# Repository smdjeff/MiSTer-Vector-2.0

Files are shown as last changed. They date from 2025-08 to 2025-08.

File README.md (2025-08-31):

## MisterArcade
## DE10-Nano adapter board for vector graphics output

* Modern, 3W mono onboard amplifier
* No slow or overclocked serial DACs. Latched, high speed, low cost R–2R ladder to perform digital-to-analog conversion
* Uses DE10-Nano GPIO1 2x20 connector for input from FPGA (GPIO2 remains free for standard MisterArcade RAM expansion)
* No USB latency
* JAMMA IO with ESD protection

* 10bit +/- 10v X output
* 10bit +/- 10v Y output
* 6bit 0-3.3v RED output
* 6bit 0-3.3v GREEN output
* 6bit 0-3.3v BLUE output

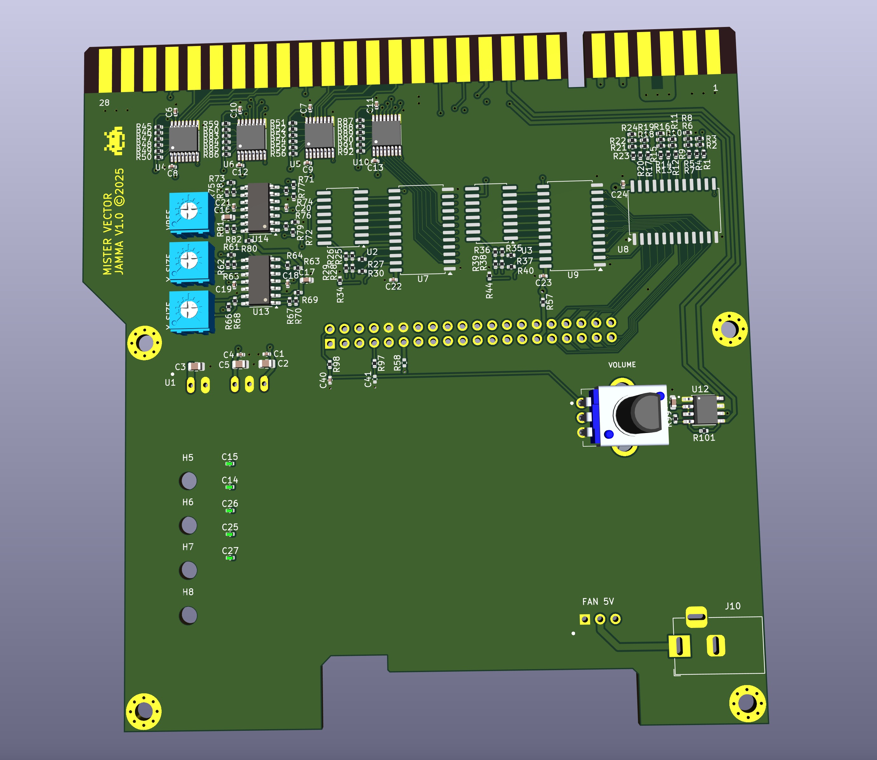
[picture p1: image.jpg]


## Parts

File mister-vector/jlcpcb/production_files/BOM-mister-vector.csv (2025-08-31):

Comment | Designator | Footprint | LCSC | Quantity
75R | R61,R62,R66,R67,R71,R72,R73,R80 | R_0402_1005Metric | C114757 | 8
475R | R97,R98 | R_0402_1005Metric | C137975 | 2
1uF | C16,C17,C47 | C_0603_1608Metric | C15849 | 3
0 | R57 | R_0402_1005Metric | C17168 | 1
4.7uF | C2,C3,C5 | C_0805_2012Metric | C1779 | 3
100k | R45,R46,R47,R48,R49,R50,R51,R52,R53,R54,R55,R56,R59,R60,R83,R84,R85,R86,R87,R88,R89,R90,R91,R92 | R_0402_1005Metric | C25741 | 24
10K | R63,R64,R65,R68,R69,R70,R74,R75,R76,R81 | R_0402_1005Metric | C25744 | 10
20k | R101,R99 | R_0402_1005Metric | C25765 | 2
4K7 | R77,R78,R79,R82 | R_0402_1005Metric | C25900 | 4
TL084HIDR | U13,U14 | SOIC-14_3.9x8.7mm_P1.27mm | C2878714 | 2
100nF | C1,C10,C11,C12,C13,C18,C19,C20,C21,C22,C23,C24,C4,C6,C7,C8,C9 | C_0402_1005Metric | C307331 | 17
TXB0106PWR | U10,U4,U5,U6 | SOP65P640X120-16N | C38253 | 4
20nF | C40 | C_0402_1005Metric | C5448807 | 1
LM4871MX_NOPB | U12 | SOIC127P599X175-8N | C7554 | 1
VREF | VR1,VR2,VR3 | TRIM_3362P-1-203LF | C81263 | 3
100k 0.1% | R1,R10,R11,R12,R13,R14,R15,R16,R17,R18,R19,R2,R20,R21,R22,R23,R24,R25,R26,R27,R28,R29,R3,R30,R31,R32,R33,R34,R35,R36,R37,R38,R39,R4,R40,R41,R42,R43,R44,R5,R6,R7,R8,R9 | R_0402_1005Metric | C852472 | 44

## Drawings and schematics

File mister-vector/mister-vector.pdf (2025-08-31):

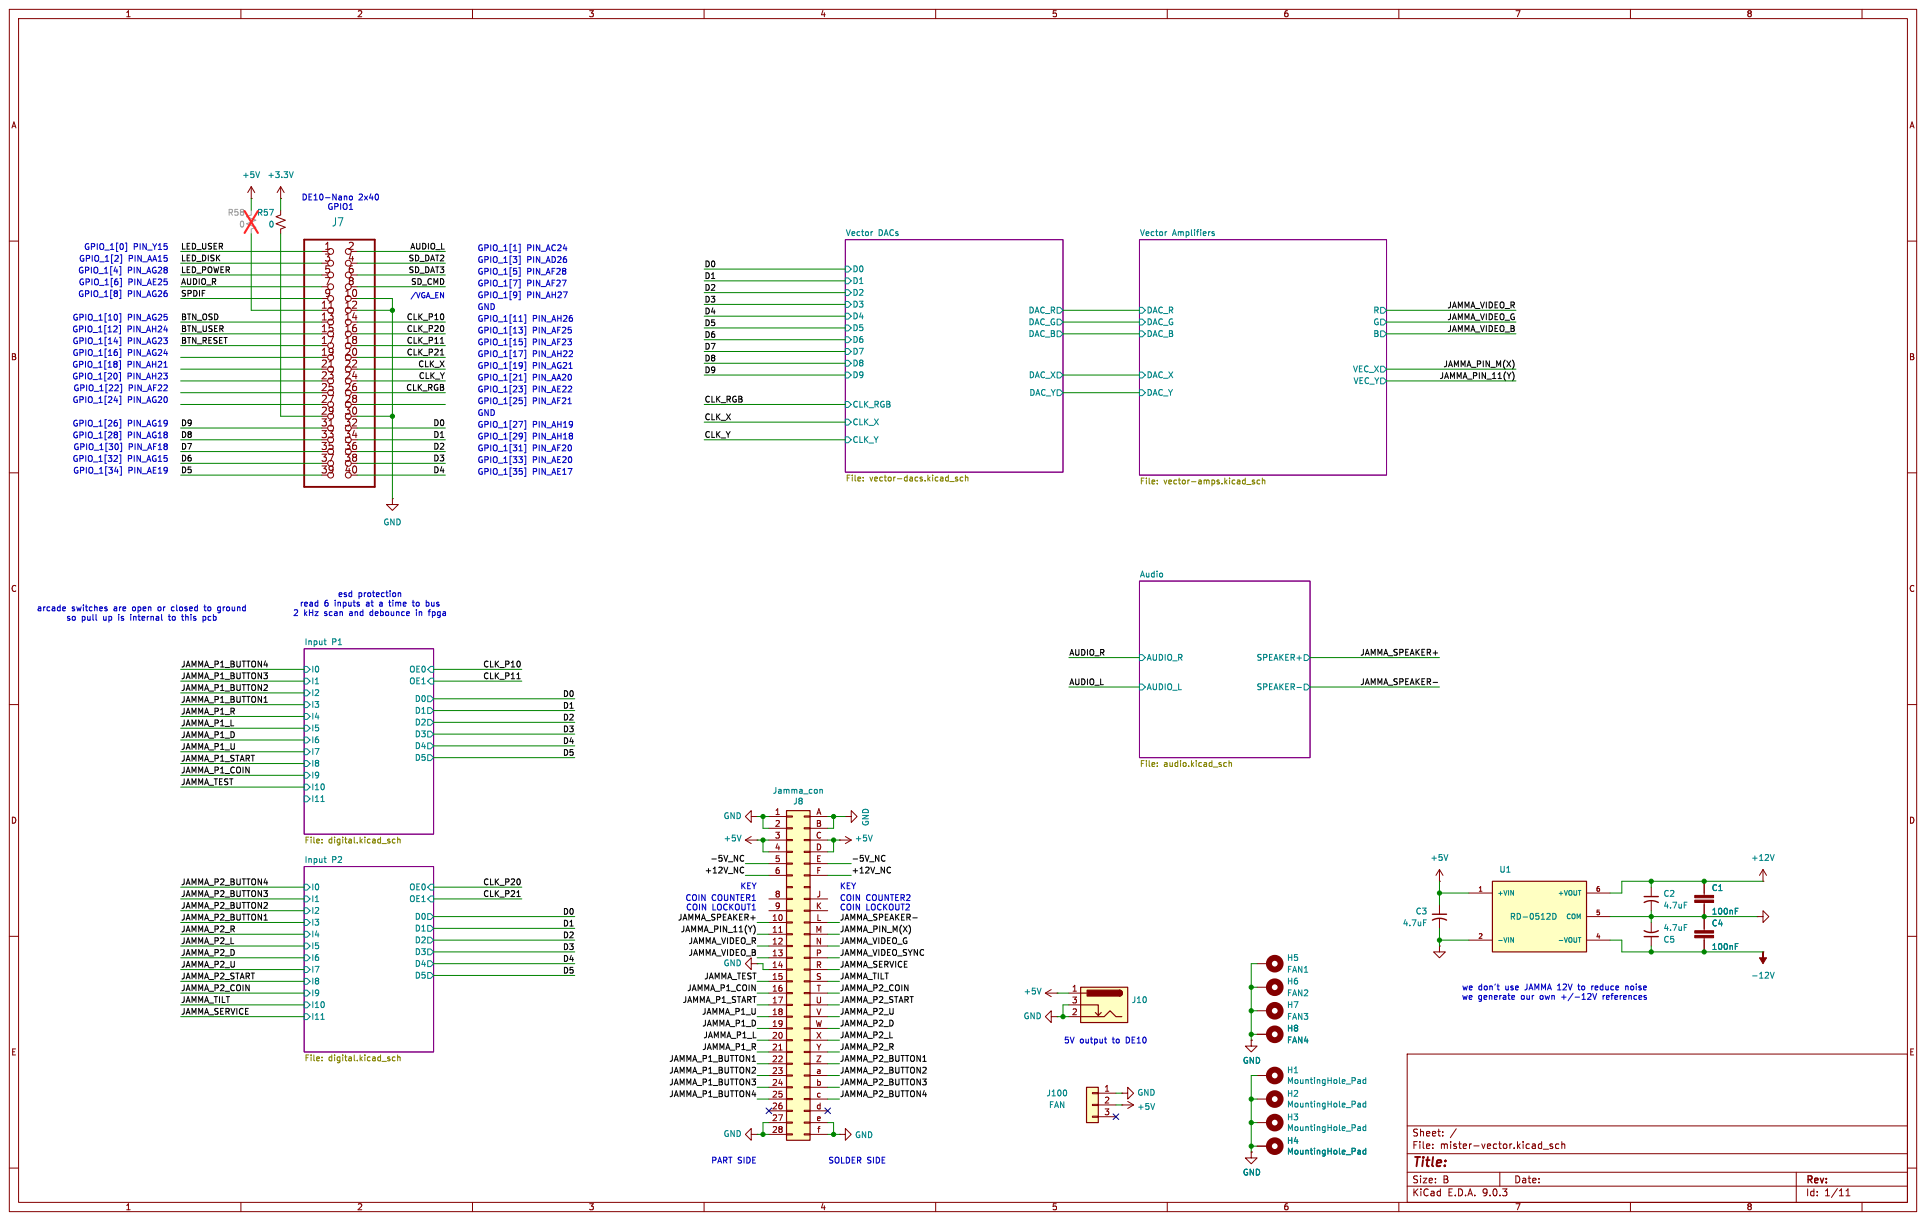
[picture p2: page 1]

Vector DACs File: vector-dacs.kicad_sch

arcade switches are open or closed to ground

read 6 inputs at a time to bus 2 kHz scan and debounce in fpga

Id: 1/11 Title: File: mister-vector.kicad_sch Sheet: /

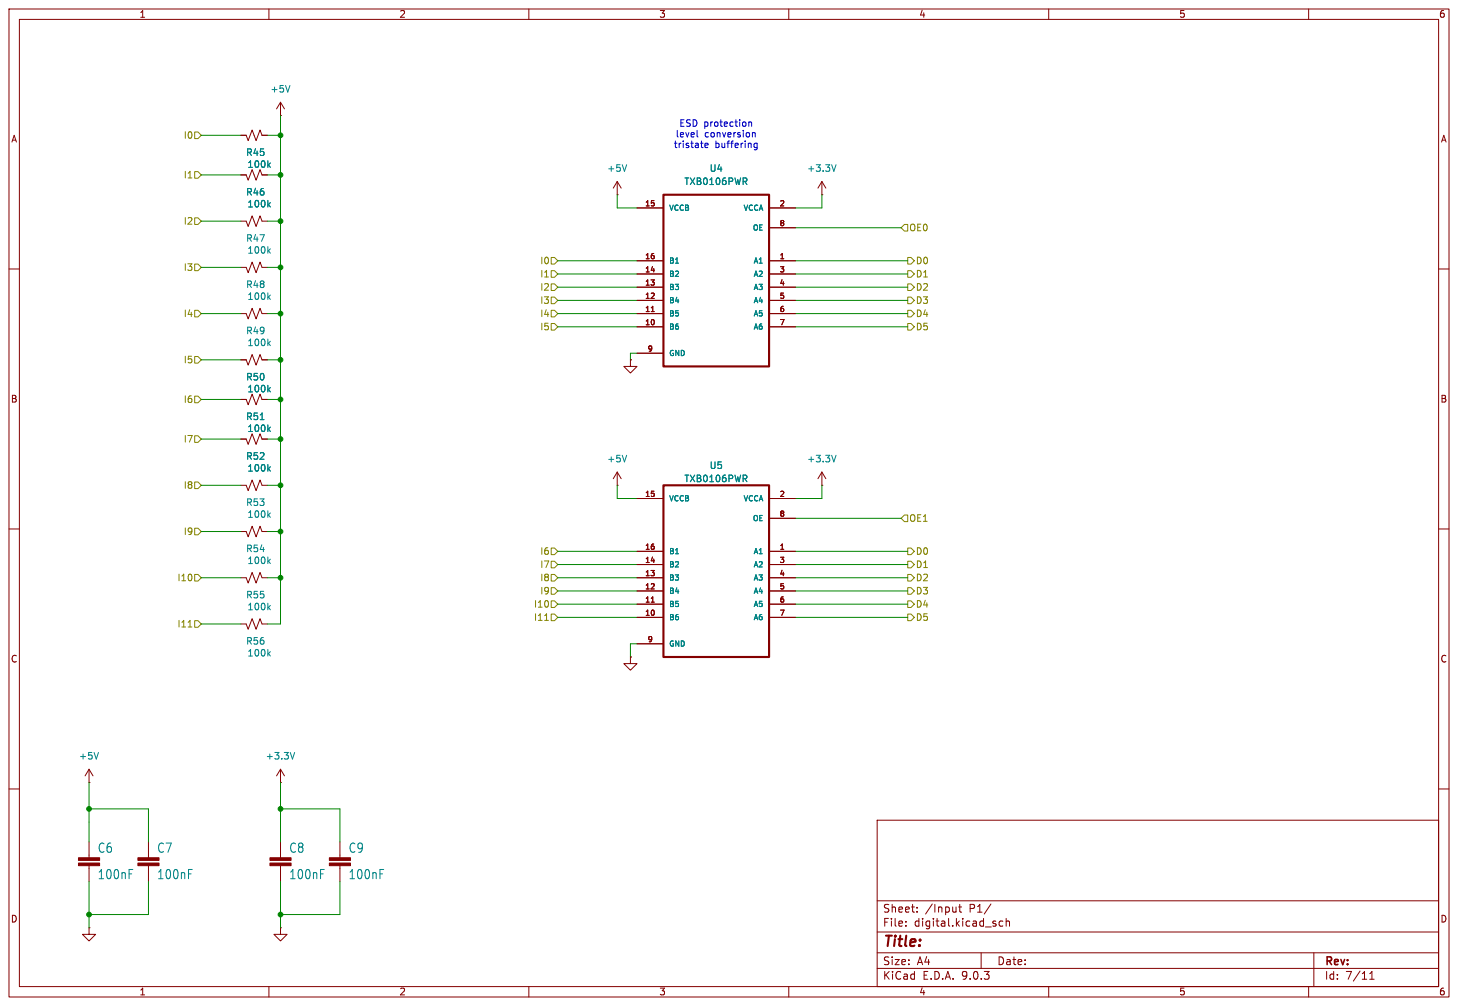
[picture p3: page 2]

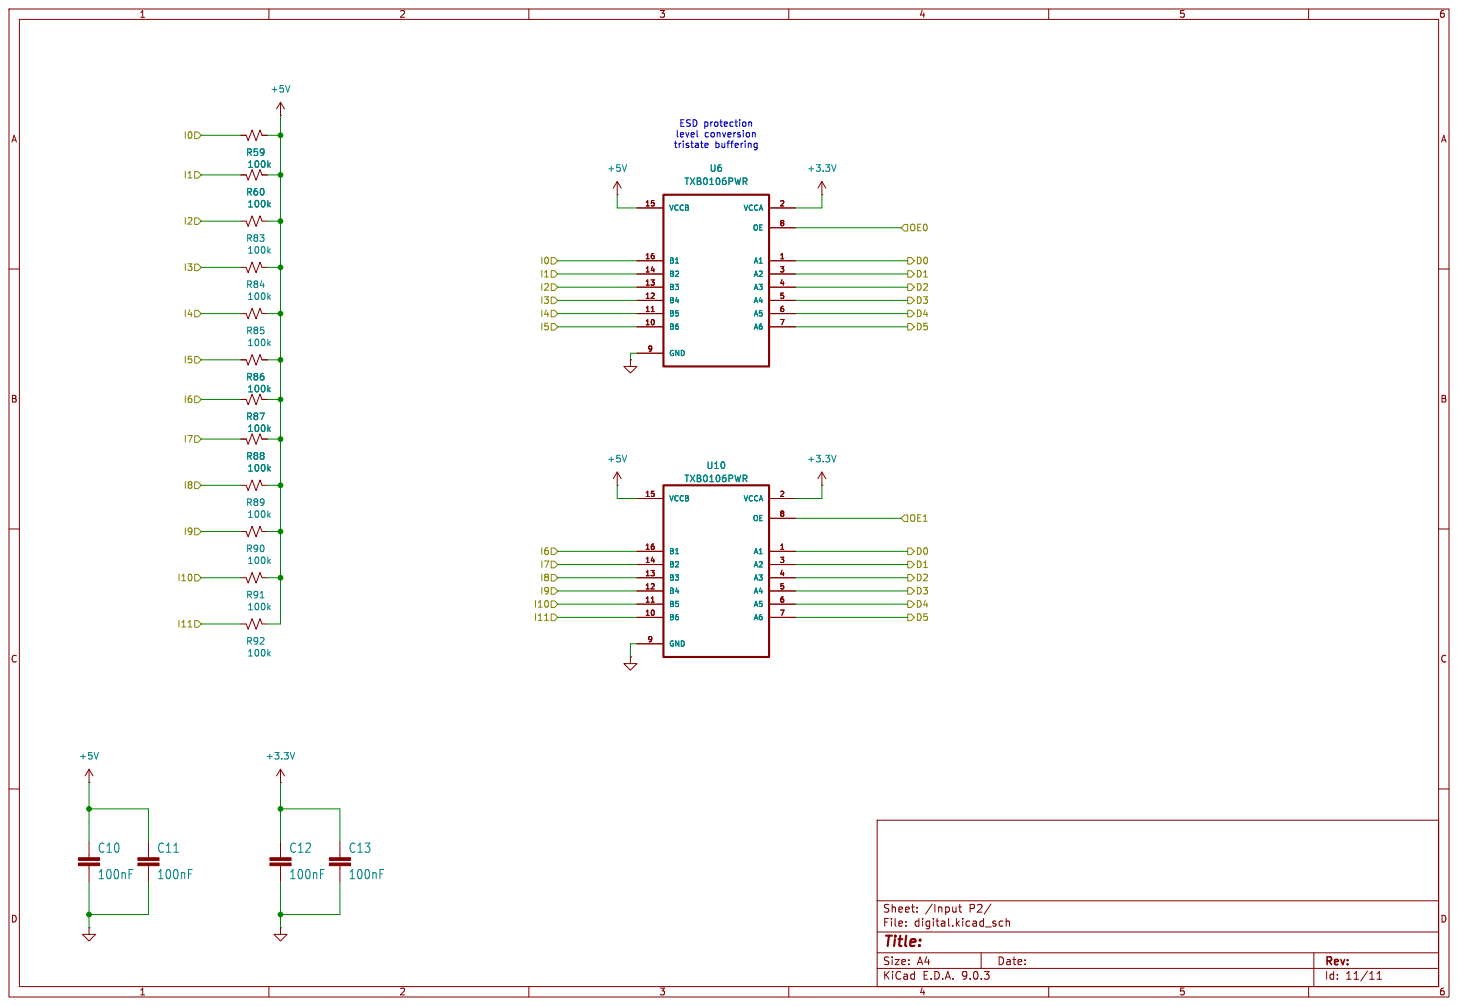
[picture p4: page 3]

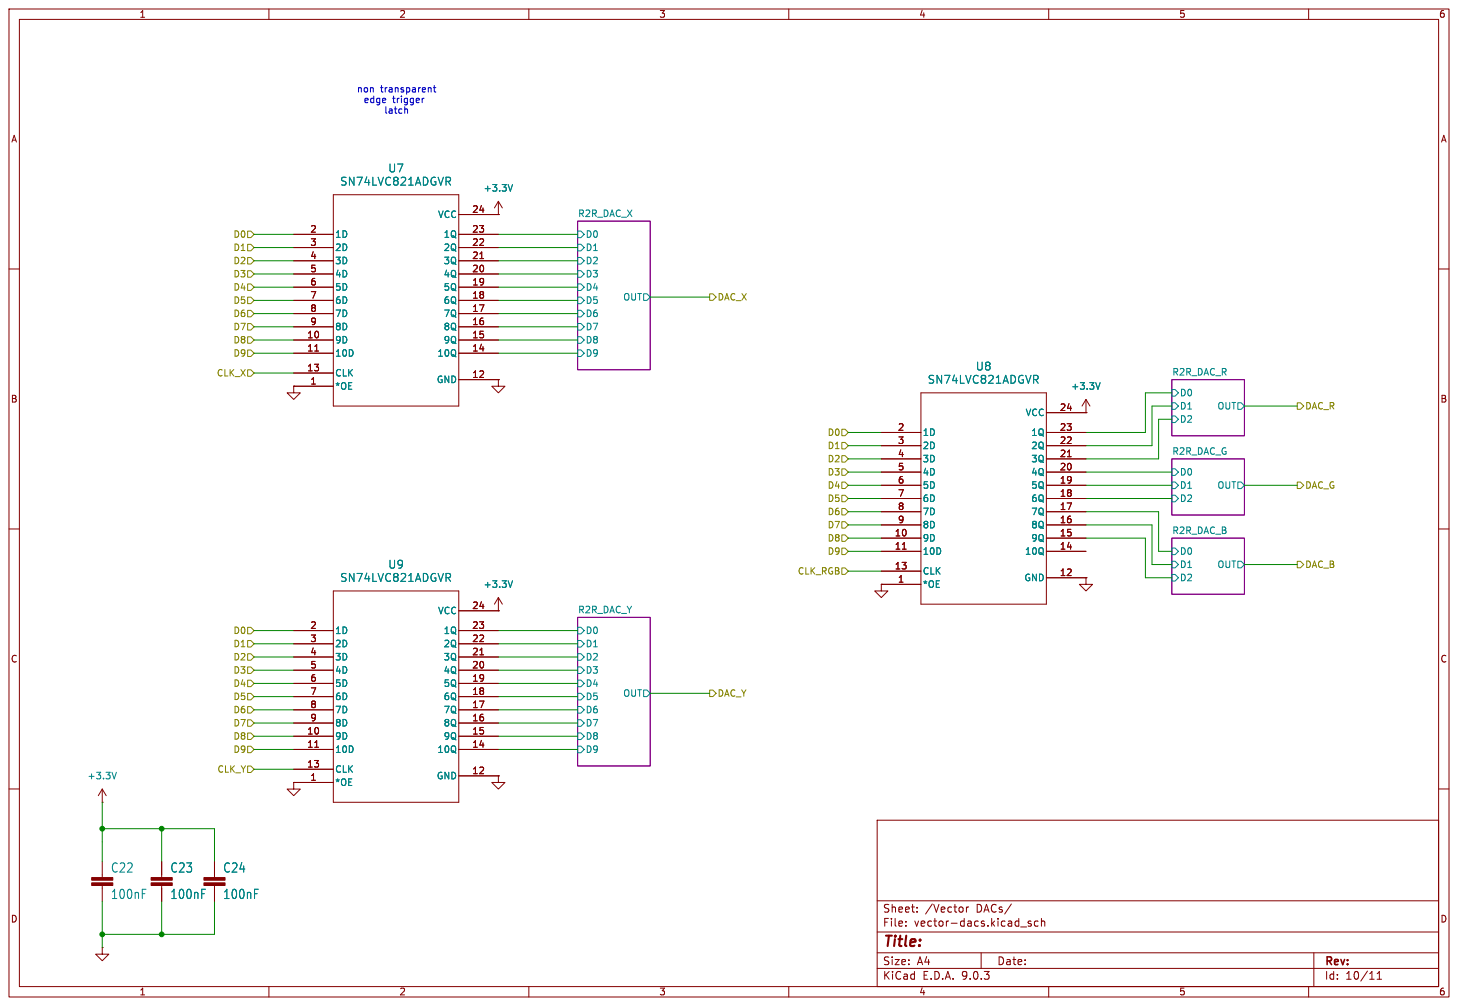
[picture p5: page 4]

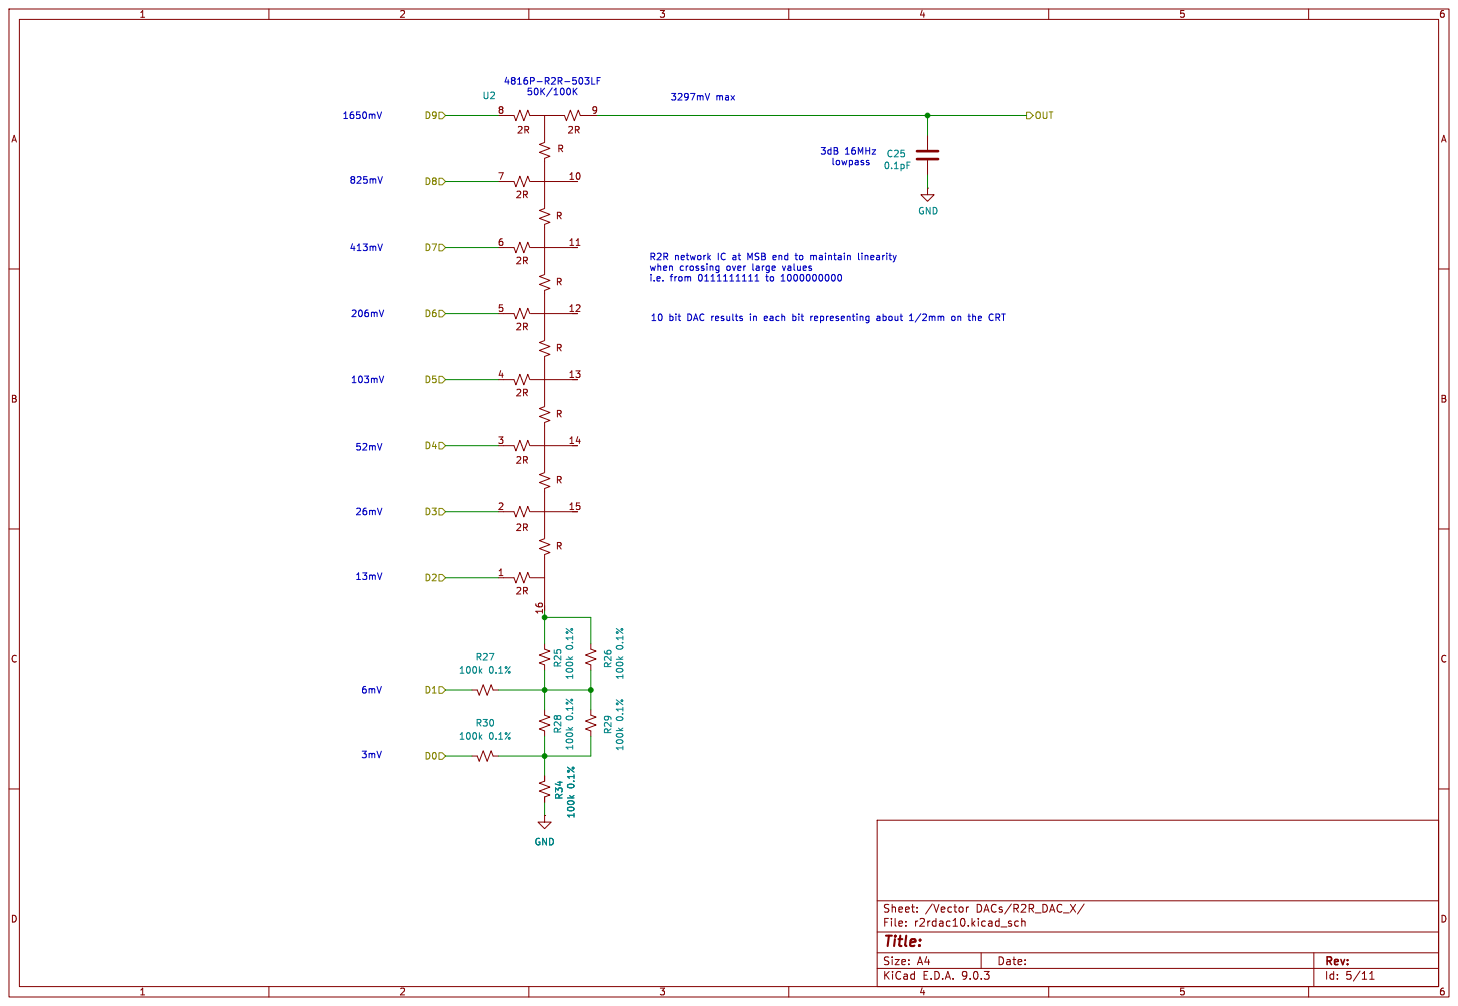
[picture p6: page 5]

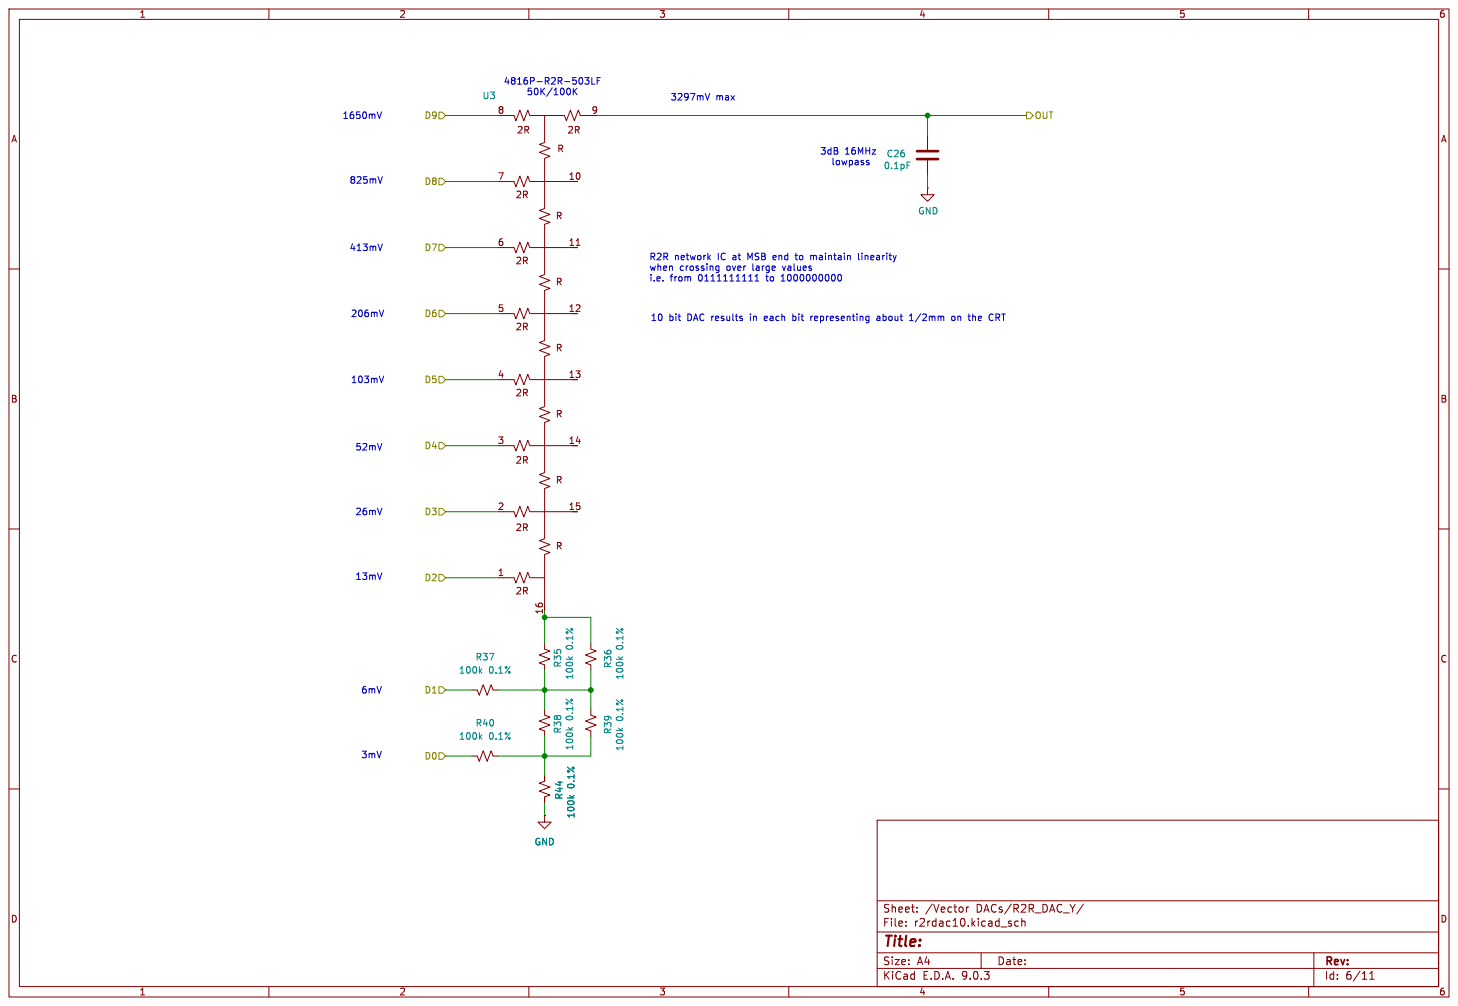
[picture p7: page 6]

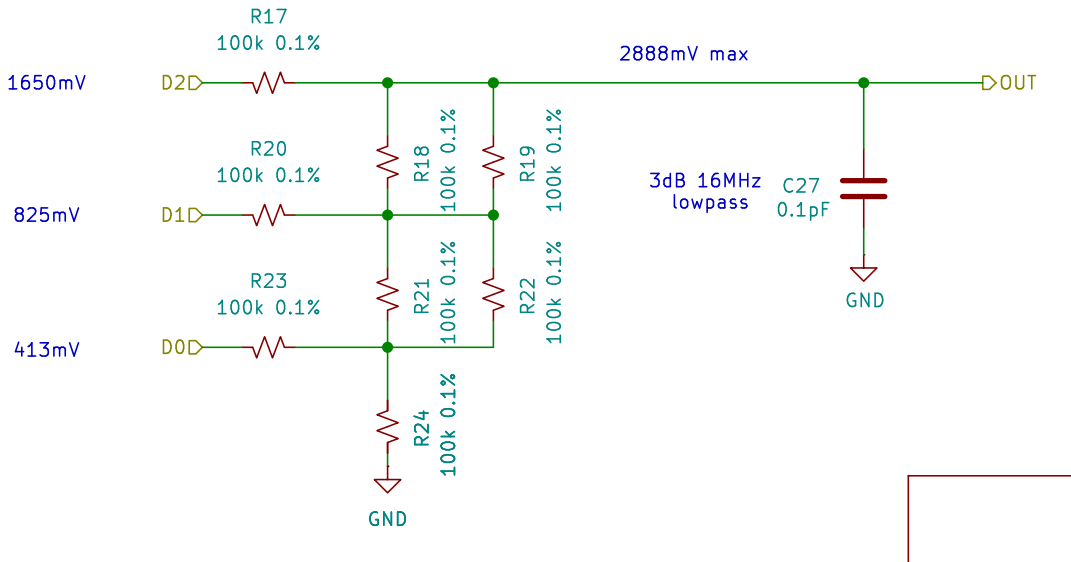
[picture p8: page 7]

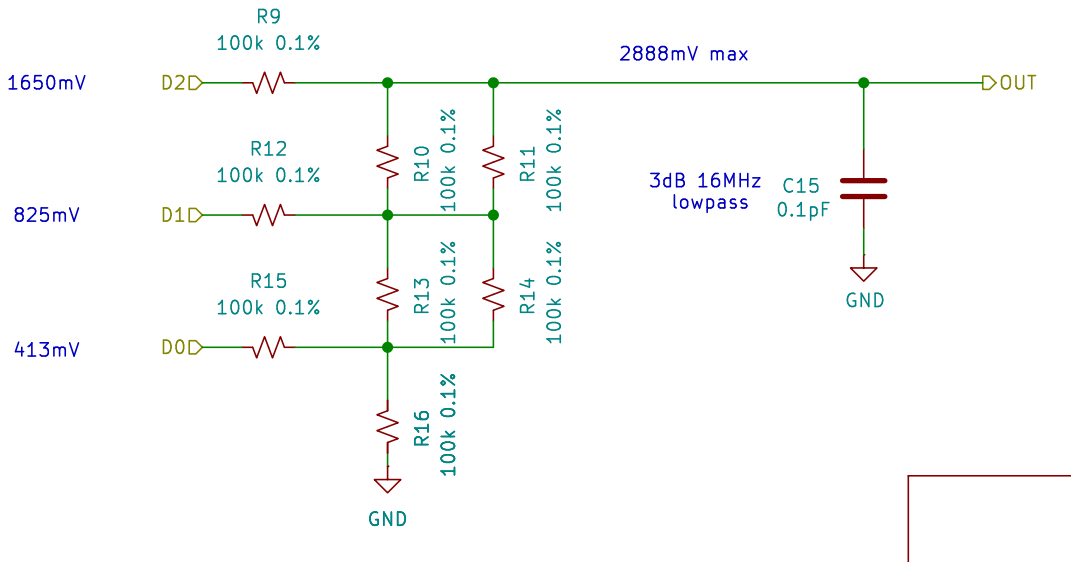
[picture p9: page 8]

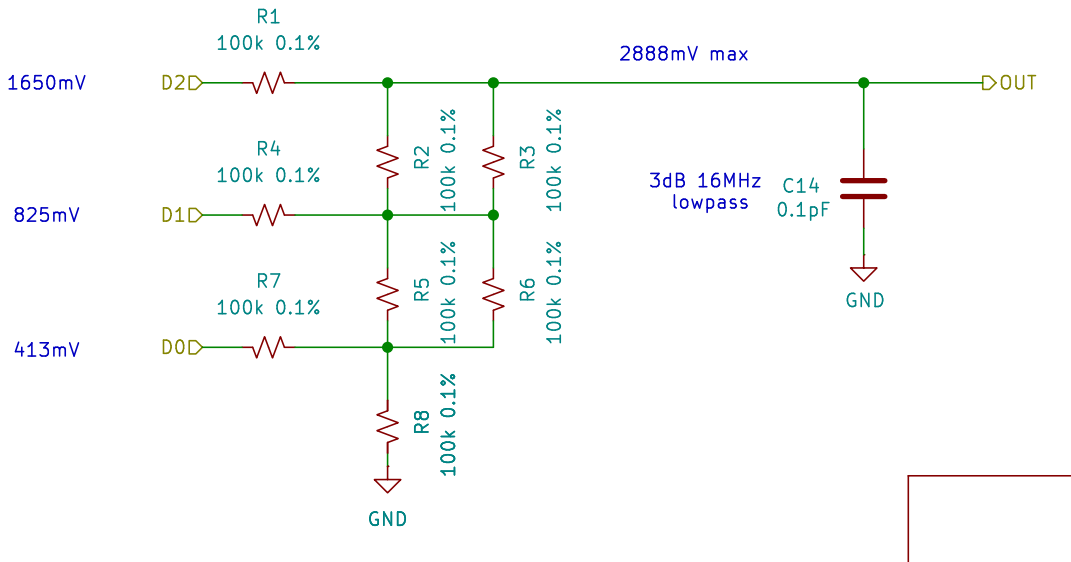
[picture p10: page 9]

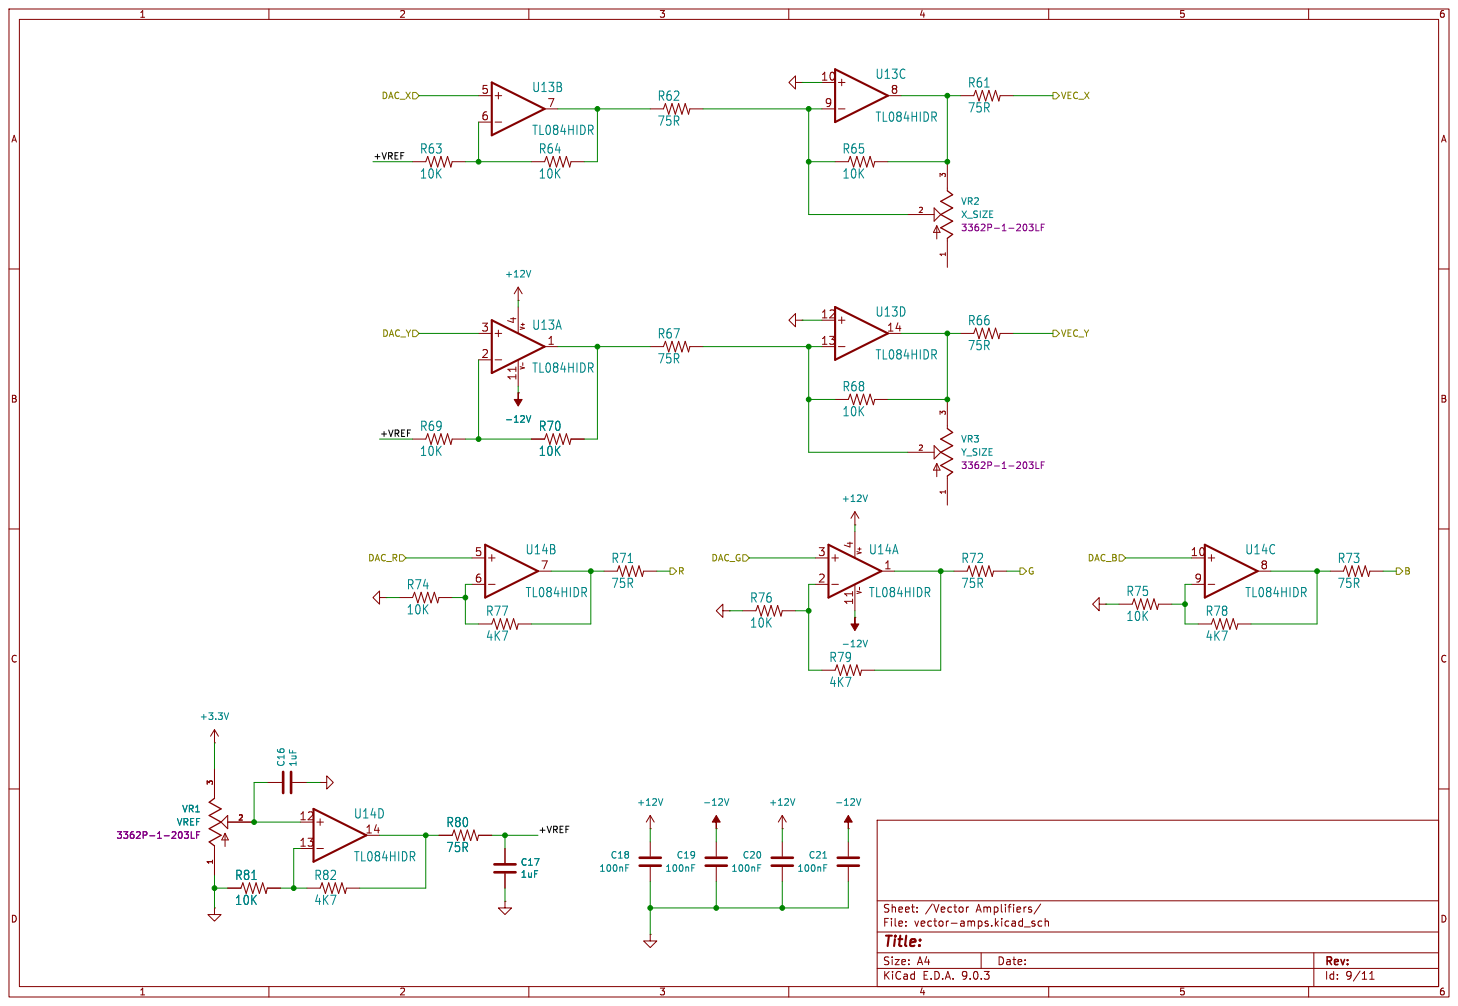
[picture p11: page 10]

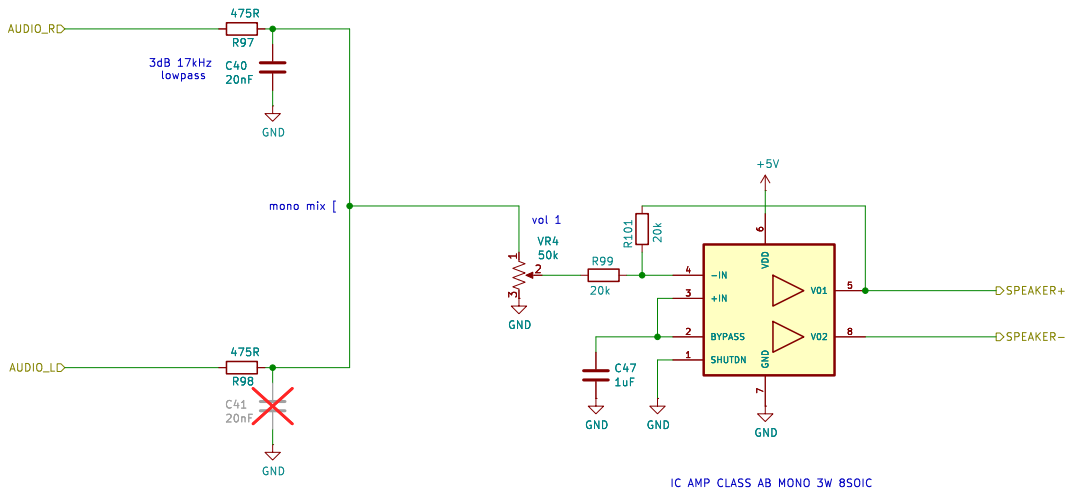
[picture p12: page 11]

IC AMP CLASS AB MONO 3W 8SOIC

Id: 8/11 Title: File: audio.kicad_sch Sheet: /Audio/

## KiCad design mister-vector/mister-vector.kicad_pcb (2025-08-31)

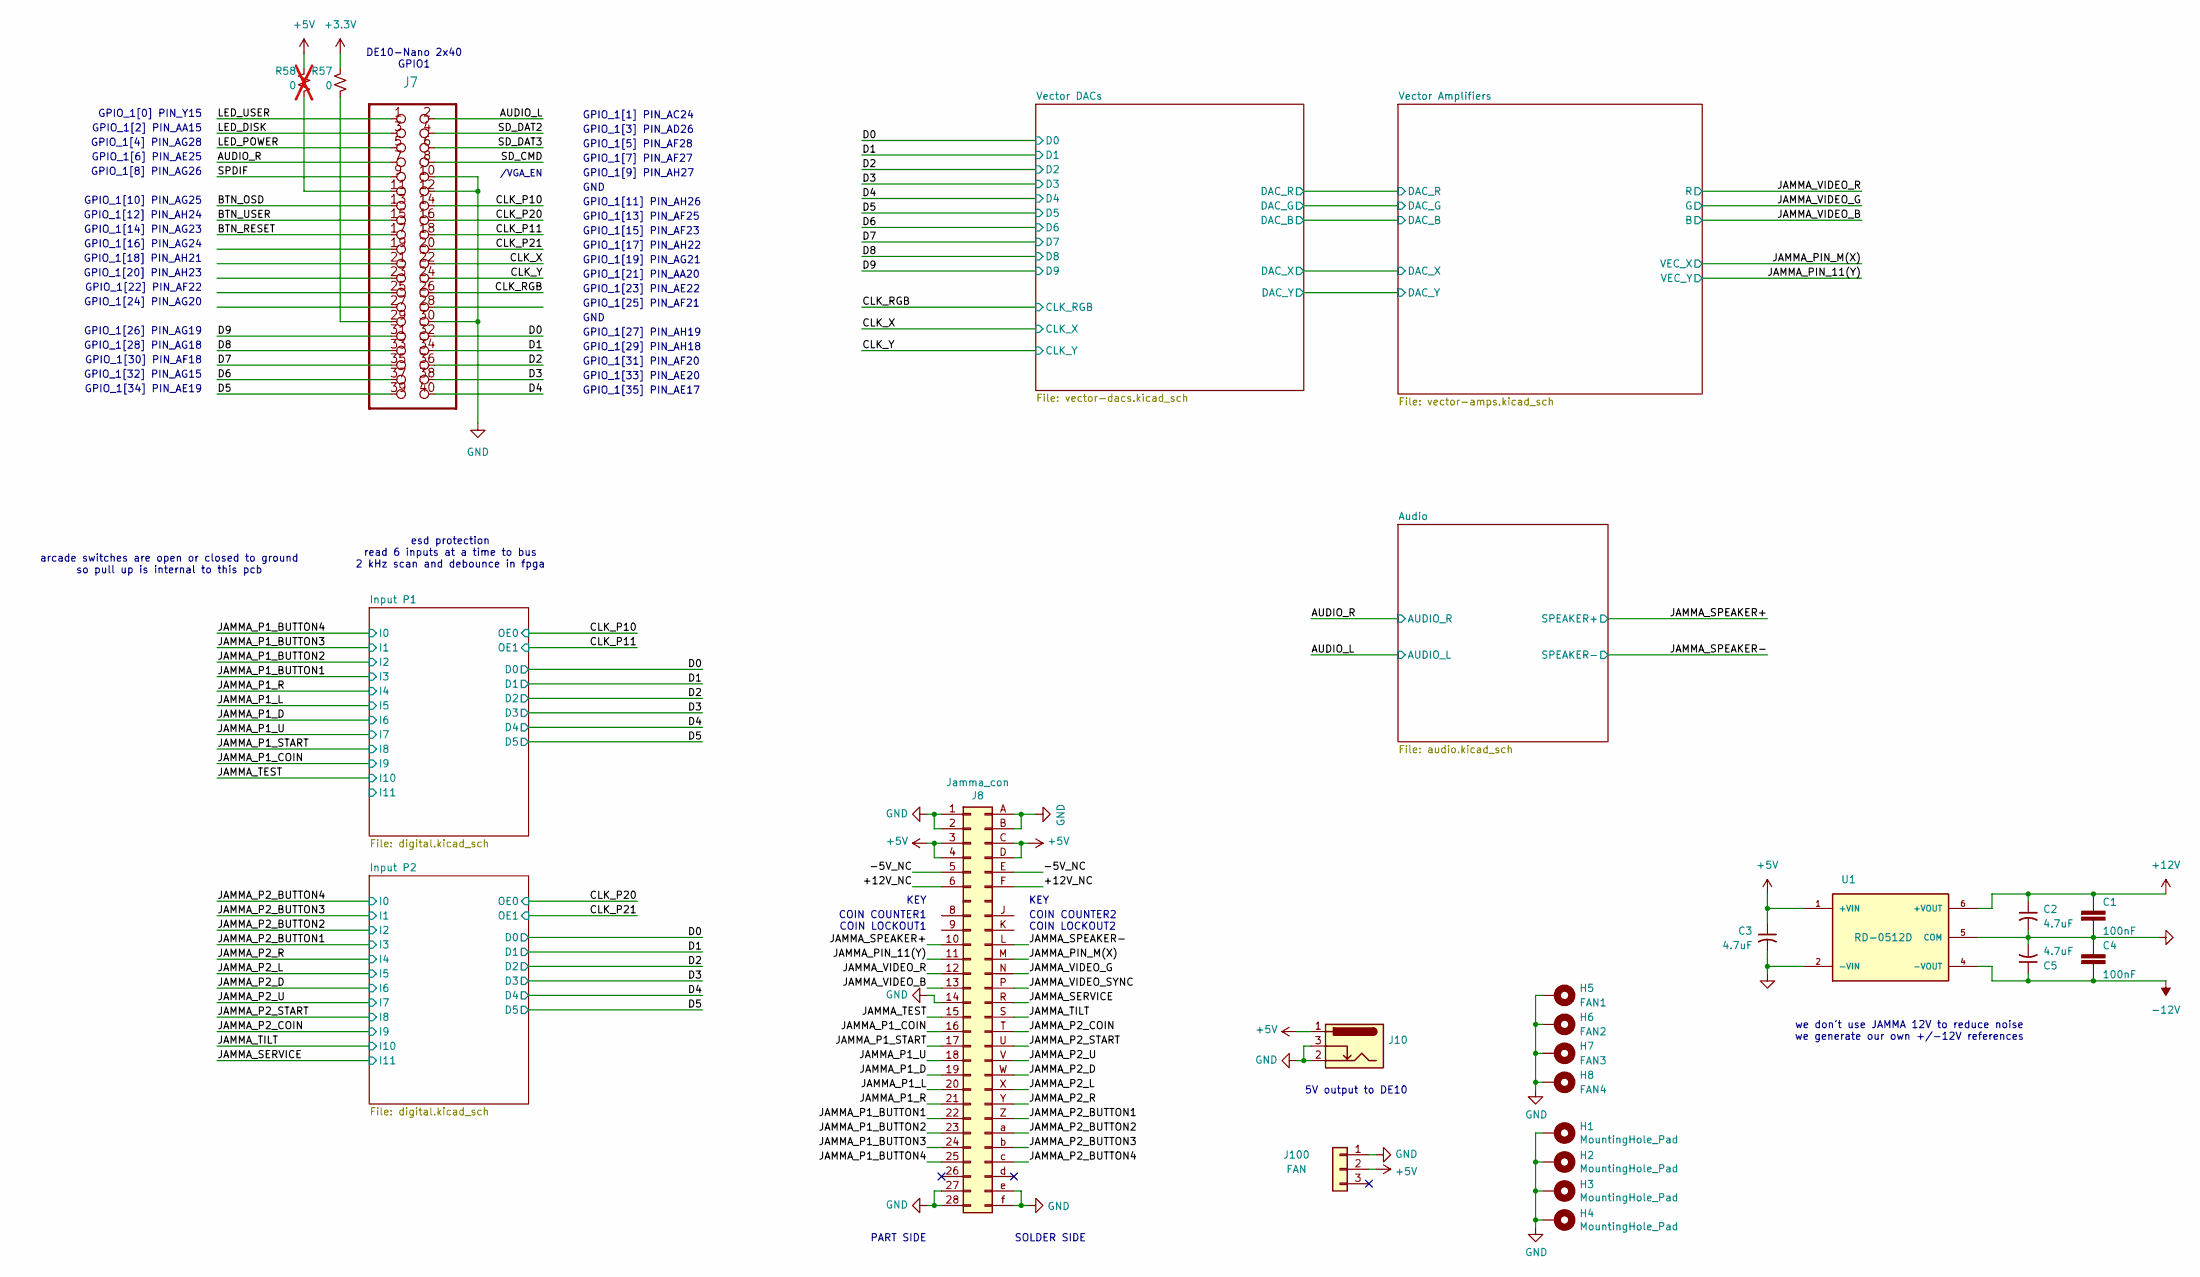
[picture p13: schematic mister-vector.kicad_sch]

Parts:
C1, C4: 100nF; C_0402_1005Metric; LCSC C307331
C2, C3, C5: 4.7uF; C_0805_2012Metric; LCSC C1779
H1, H2, H3, H4: MountingHole_Pad; MountingHole_3mm_Pad_Via
H5: FAN1; MountingHole_3mm
H6: FAN2; MountingHole_3mm
H7: FAN3; MountingHole_3mm
H8: FAN4; MountingHole_3mm
J7: PINHD-2X20; 2X20
J8: Jamma_con; JAMMA-56
J10: DC-005-2.5A-2.0 C319099; BarrelJack_Horizontal
J100: FAN; PinHeader_1x03_P2.54mm_Vertical
R57: 0; R_0402_1005Metric; LCSC C17168
R58: 0; R_0402_1005Metric; LCSC C17168; not fitted
U1: RD-0512D; CONV_RD-0512D; PARTREV 1; LCSC C5721603

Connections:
+3.3V: R57.1; also elsewhere on the board
+5V: C3.1, J8.3 (+5V), J8.4 (+5V), J8.C (+5V), J8.D (+5V), J10.1, J100.2, R58.1, U1.1 (+VIN); also elsewhere on the board
+12V: C1.1, C2.1, U1.6 (+VOUT); also elsewhere on the board
-12V: C4.2, C5.1, U1.4 (-VOUT); also elsewhere on the board
/+12V_NC: J8.6 (+12V), J8.F (+12V)
/-5V_NC: J8.5 (-5V), J8.E (-5V)
/AUDIO_L: J7.2; also elsewhere on the board
/AUDIO_R: J7.7; also elsewhere on the board
/BTN_OSD: J7.13
/BTN_RESET: J7.17
/BTN_USER: J7.15
/CLK_P10: J7.14; also elsewhere on the board
/CLK_P11: J7.18; also elsewhere on the board
/CLK_P20: J7.16; also elsewhere on the board
/CLK_P21: J7.20; also elsewhere on the board
/CLK_RGB: J7.26; also elsewhere on the board
/CLK_X: J7.22; also elsewhere on the board
/CLK_Y: J7.24; also elsewhere on the board
/D0: J7.32; also elsewhere on the board
/D1: J7.34; also elsewhere on the board
/D2: J7.36; also elsewhere on the board
/D3: J7.38; also elsewhere on the board
/D4: J7.40; also elsewhere on the board
/D5: J7.39; also elsewhere on the board
/D6: J7.37; also elsewhere on the board
/D7: J7.35; also elsewhere on the board
/D8: J7.33; also elsewhere on the board
/D9: J7.31; also elsewhere on the board
/JAMMA_P1_BUTTON1: J8.22 (P1_BUTTON_1); also elsewhere on the board
/JAMMA_P1_BUTTON2: J8.23 (P1_BUTTON_2); also elsewhere on the board
/JAMMA_P1_BUTTON3: J8.24 (P1_BUTTON_3); also elsewhere on the board
/JAMMA_P1_BUTTON4: J8.25 (P1_BUTTON_4); also elsewhere on the board
/JAMMA_P1_COIN: J8.16 (COIN_1); also elsewhere on the board
/JAMMA_P1_D: J8.19 (P1_DOWN); also elsewhere on the board
/JAMMA_P1_L: J8.20 (P1_LEFT); also elsewhere on the board
/JAMMA_P1_R: J8.21 (P1_RIGHT); also elsewhere on the board
/JAMMA_P1_START: J8.17 (START_1); also elsewhere on the board
/JAMMA_P1_U: J8.18 (P1_UP); also elsewhere on the board
/JAMMA_P2_BUTTON1: J8.Z (P2_BUTTON_1); also elsewhere on the board
/JAMMA_P2_BUTTON2: J8.a (P2_BUTTON_2); also elsewhere on the board
/JAMMA_P2_BUTTON3: J8.b (P2_BUTTON_3); also elsewhere on the board
/JAMMA_P2_BUTTON4: J8.c (P2_BUTTON_4); also elsewhere on the board
/JAMMA_P2_COIN: J8.T (COIN_2); also elsewhere on the board
/JAMMA_P2_D: J8.W (P2_DOWN); also elsewhere on the board
/JAMMA_P2_L: J8.X (P2_LEFT); also elsewhere on the board
/JAMMA_P2_R: J8.Y (P2_RIGHT); also elsewhere on the board
/JAMMA_P2_START: J8.U (START_2); also elsewhere on the board
/JAMMA_P2_U: J8.V (P2_UP); also elsewhere on the board
/JAMMA_PIN_11(Y): J8.11 (AUDIO+); also elsewhere on the board
/JAMMA_PIN_M(X): J8.M (TEST); also elsewhere on the board
/JAMMA_SERVICE: J8.R (SERVICE); also elsewhere on the board
/JAMMA_SPEAKER+: J8.10 (SPEAKER+); also elsewhere on the board
/JAMMA_SPEAKER-: J8.L (SPEAKER-); also elsewhere on the board
/JAMMA_TEST: J8.15 (COIN_3); also elsewhere on the board
/JAMMA_TILT: J8.S (COIN_4); also elsewhere on the board
/JAMMA_VIDEO_B: J8.13 (VIDEO_BLUE); also elsewhere on the board
/JAMMA_VIDEO_G: J8.N (VIDEO_GREEN); also elsewhere on the board
/JAMMA_VIDEO_R: J8.12 (VIDEO_RED); also elsewhere on the board
/JAMMA_VIDEO_SYNC: J8.P (VIDEO_SYNC)
/LED_DISK: J7.3
/LED_POWER: J7.5
/LED_USER: J7.1
/SD_CMD: J7.8
/SD_DAT2: J7.4
/SD_DAT3: J7.6
/SPDIF: J7.9
GND: C1.2, C2.2, C3.2, C4.1, C5.2, H1.1, H2.1, H3.1, H4.1, H5.1, H6.1, H7.1, H8.1, J7.10, J7.12, J7.30, J8.1 (GND), J8.2 (GND), J8.14 (VIDEO_GND), J8.27 (GND), J8.28 (GND), J8.A (GND), J8.B (GND), J8.e (GND), J8.f (GND), J10.2, J10.3, J100.1, U1.2 (-VIN), U1.5 (COM); also elsewhere on the board
unnamed: J7.11, R58.2
unnamed: J7.29, R57.2

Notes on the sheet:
GPIO_1[12] PIN_AH24
GPIO_1[15] PIN_AF23
GPIO_1[32] PIN_AG15
GPIO_1[7] PIN_AF27
SOLDER SIDE
GPIO_1[31] PIN_AF20
KEY
GPIO_1[27] PIN_AH19
GPIO_1[2] PIN_AA15
COIN LOCKOUT1
GPIO_1[23] PIN_AE22
GPIO_1[8] PIN_AG26
GPIO_1[29] PIN_AH18
GPIO_1[5] PIN_AF28
GPIO_1[1] PIN_AC24
GPIO_1[24] PIN_AG20
/VGA_EN
COIN LOCKOUT2
GPIO_1[25] PIN_AF21
GPIO_1[26] PIN_AG19
GND
GPIO_1[11] PIN_AH26
GPIO_1[21] PIN_AA20
GPIO_1[16] PIN_AG24
GPIO_1[0] PIN_Y15
GPIO_1[14] PIN_AG23
esd protection read 6 inputs at a time to bus 2 kHz scan and debounce in fpga
COIN COUNTER1
GPIO_1[19] PIN_AG21
GPIO_1[6] PIN_AE25
DE10-Nano 2x40 GPIO1
GPIO_1[10] PIN_AG25
GPIO_1[34] PIN_AE19
GPIO_1[35] PIN_AE17
GPIO_1[4] PIN_AG28
GPIO_1[33] PIN_AE20
GPIO_1[3] PIN_AD26
arcade switches are open or closed to ground so pull up is internal to this pcb
GPIO_1[13] PIN_AF25
GPIO_1[20] PIN_AH23

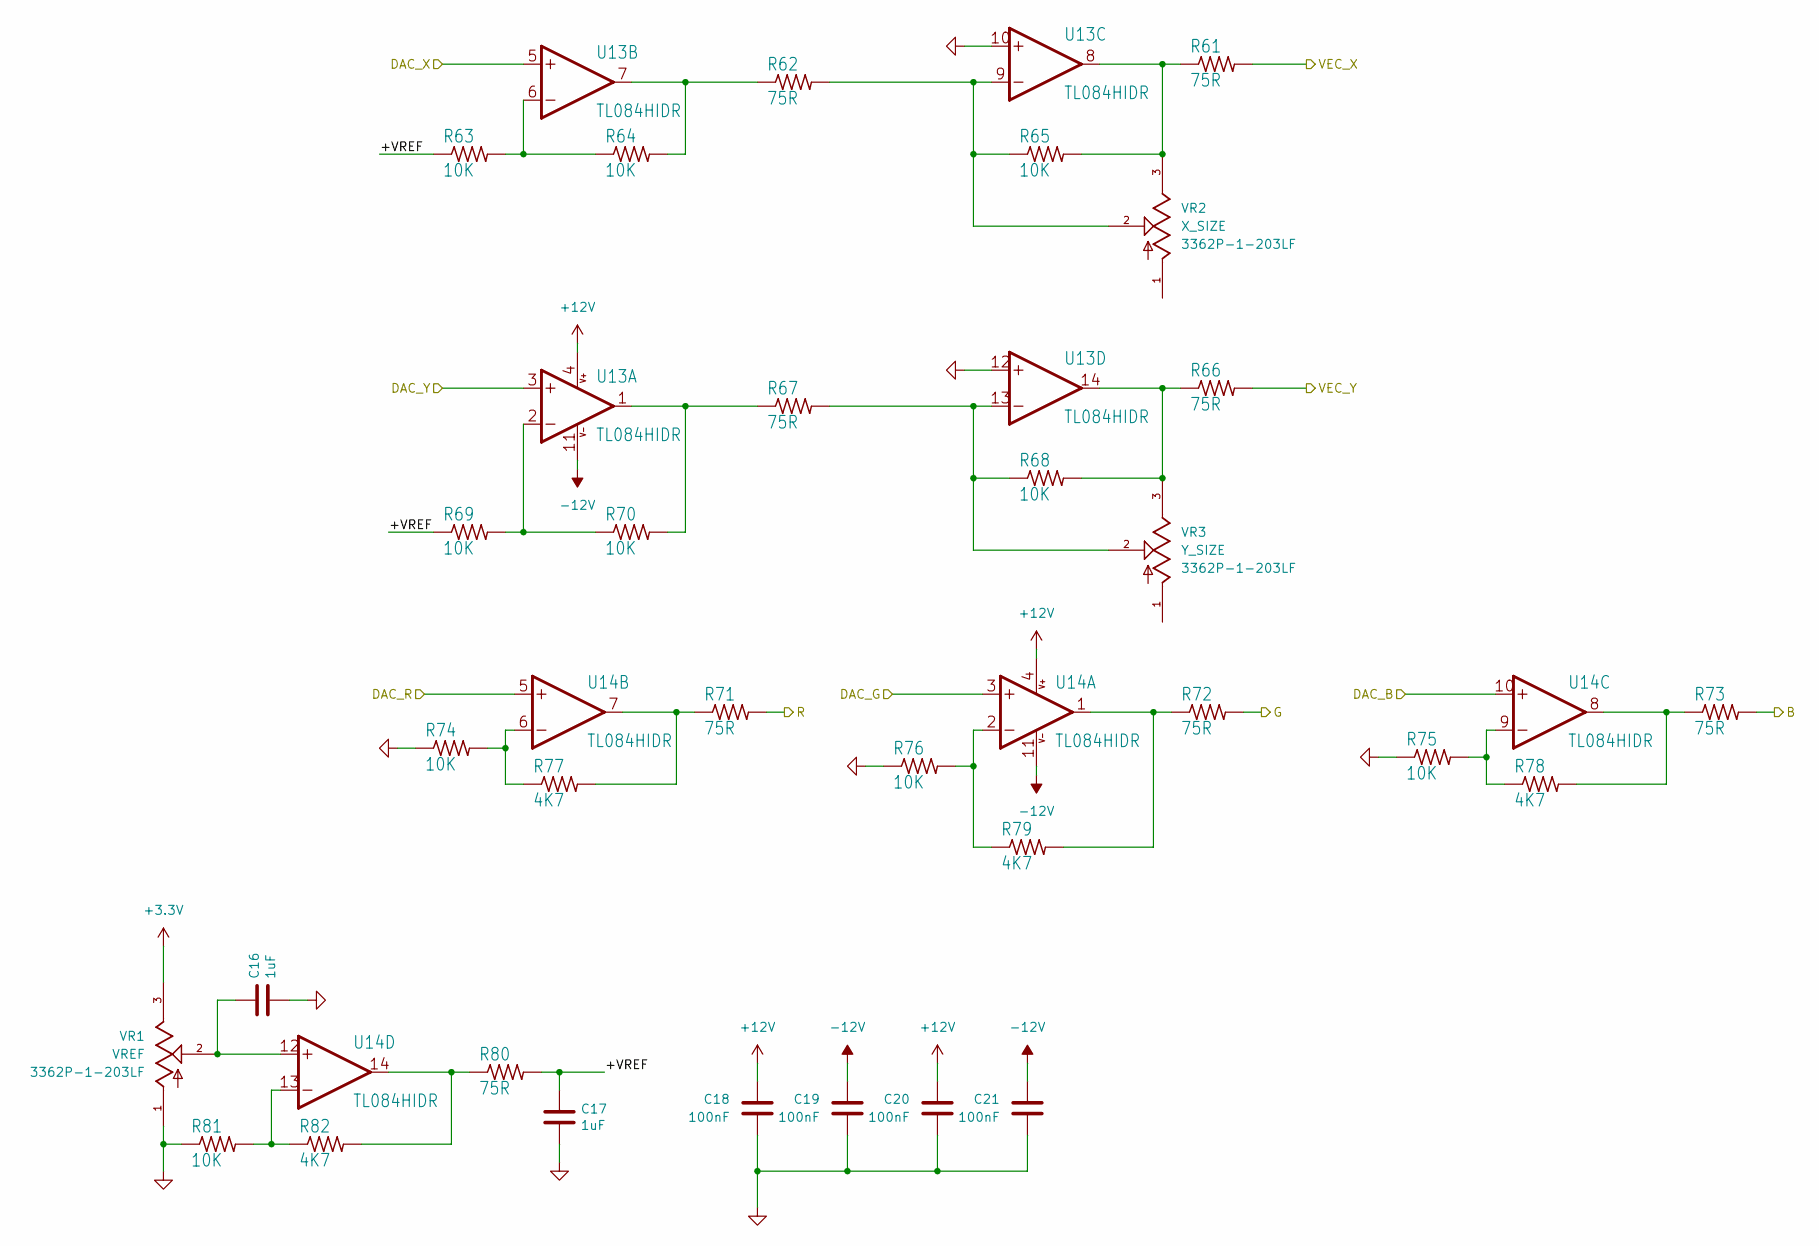
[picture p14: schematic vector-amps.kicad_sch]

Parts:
C16, C17: 1uF; C_0603_1608Metric; LCSC C15849
C18, C19, C20, C21: 100nF; C_0402_1005Metric; LCSC C307331
R61, R62, R66, R67, R71, R72, R73, R80: 75R; R0603; LCSC C114757
R63, R64, R65, R68, R69, R70, R74, R75, R76, R81: 10K; R0603; LCSC C25744
R77, R78, R79, R82: 4K7; R0603; LCSC C25900
U13, U14: TL084HIDR; SOIC-14_3.9x8.7mm_P1.27mm; LCSC C2878714
VR1: VREF; TRIM_3362P-1-203LF; LCSC C81263
VR2: X_SIZE; TRIM_3362P-1-203LF; LCSC C81263
VR3: Y_SIZE; TRIM_3362P-1-203LF; LCSC C81263

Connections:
+3.3V: VR1.3; also elsewhere on the board
+12V: C18.2, C20.2, U13.4 (V+), U14.4 (V+); also elsewhere on the board
-12V: C19.2, C21.2, U13.11 (V-), U14.11 (V-); also elsewhere on the board
/JAMMA_PIN_11(Y): R66.2; also elsewhere on the board
/JAMMA_PIN_M(X): R61.2; also elsewhere on the board
/JAMMA_VIDEO_B: R73.2; also elsewhere on the board
/JAMMA_VIDEO_G: R72.2; also elsewhere on the board
/JAMMA_VIDEO_R: R71.2; also elsewhere on the board
/Vector Amplifiers/+VREF: C17.1, R63.1, R69.1, R80.2
/Vector Amplifiers/DAC_B: U14.10 (+IN); also elsewhere on the board
/Vector Amplifiers/DAC_G: U14.3 (+IN); also elsewhere on the board
/Vector Amplifiers/DAC_R: U14.5 (+IN); also elsewhere on the board
/Vector Amplifiers/DAC_X: U13.5 (+IN); also elsewhere on the board
/Vector Amplifiers/DAC_Y: U13.3 (+IN); also elsewhere on the board
GND: C16.2, C17.2, C18.1, C19.1, C20.1, C21.1, R74.1, R75.1, R76.1, R81.1, U13.10 (+IN), U13.12 (+IN), VR1.1; also elsewhere on the board
unnamed: R69.2, R70.1, U13.2 (-IN)
unnamed: R67.1, R70.2, U13.1 (OUT)
unnamed: R63.2, R64.1, U13.6 (-IN)
unnamed: R62.1, R64.2, U13.7 (OUT)
unnamed: R62.2, R65.1, U13.9 (-IN), VR2.2
unnamed: R61.1, R65.2, U13.8 (OUT), VR2.3
unnamed: R67.2, R68.1, U13.13 (-IN), VR3.2
unnamed: R66.1, R68.2, U13.14 (OUT), VR3.3
unnamed: R76.2, R79.1, U14.2 (-IN)
unnamed: R72.1, R79.2, U14.1 (OUT)
unnamed: R74.2, R77.1, U14.6 (-IN)
unnamed: R71.1, R77.2, U14.7 (OUT)
unnamed: R75.2, R78.1, U14.9 (-IN)
unnamed: R73.1, R78.2, U14.8 (OUT)
unnamed: C16.1, U14.12 (+IN), VR1.2
unnamed: R81.2, R82.1, U14.13 (-IN)
unnamed: R80.1, R82.2, U14.14 (OUT)

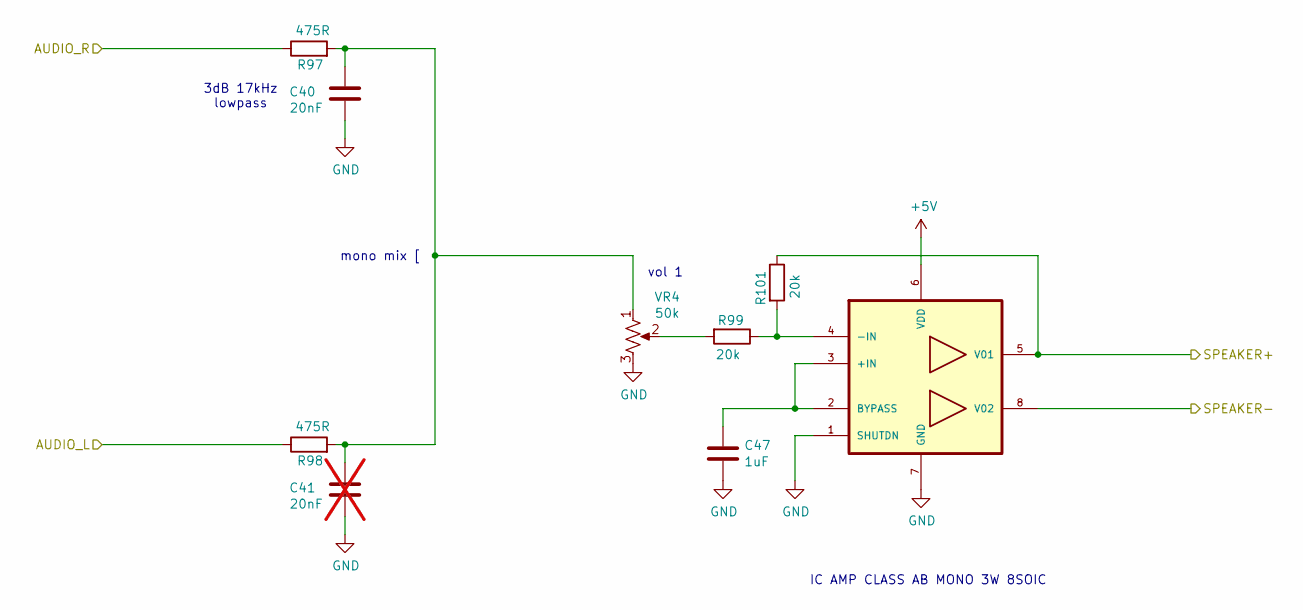
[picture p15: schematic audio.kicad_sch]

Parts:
C40: 20nF; C_0402_1005Metric; LCSC C5448807
C41: 20nF; C_0402_1005Metric; LCSC C5448807; not fitted
C47: 1uF; C_0603_1608Metric; LCSC C15849
R97, R98: 475R; R_0402_1005Metric; LCSC C137975
R99, R101: 20k; R_0402_1005Metric; LCSC C25765
U12: LM4871MX_NOPB; SOIC127P599X175-8N; LCSC C7554
VR4: 50k; PTV09A4020FB103; Manufacturer_Part_Number PTV09A-4020U-A503; Mouser Part Number 652-PTV09A-4020UA503

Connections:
+5V: U12.6 (VDD); also elsewhere on the board
/AUDIO_L: R98.1; also elsewhere on the board
/AUDIO_R: R97.1; also elsewhere on the board
/JAMMA_SPEAKER+: R101.1, U12.5 (V01); also elsewhere on the board
/JAMMA_SPEAKER-: U12.8 (V02); also elsewhere on the board
GND: C40.1, C41.1, C47.2, U12.1 (SHUTDN), U12.7 (GND), VR4.3; also elsewhere on the board
unnamed: C40.2, C41.2, R97.2, R98.2, VR4.1
unnamed: R99.2, VR4.2
unnamed: C47.1, U12.2 (BYPASS), U12.3 (+IN)
unnamed: R99.1, R101.2, U12.4 (-IN)

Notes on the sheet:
3dB 17kHz lowpass
IC AMP CLASS AB MONO 3W 8SOIC
vol 1
mono mix [

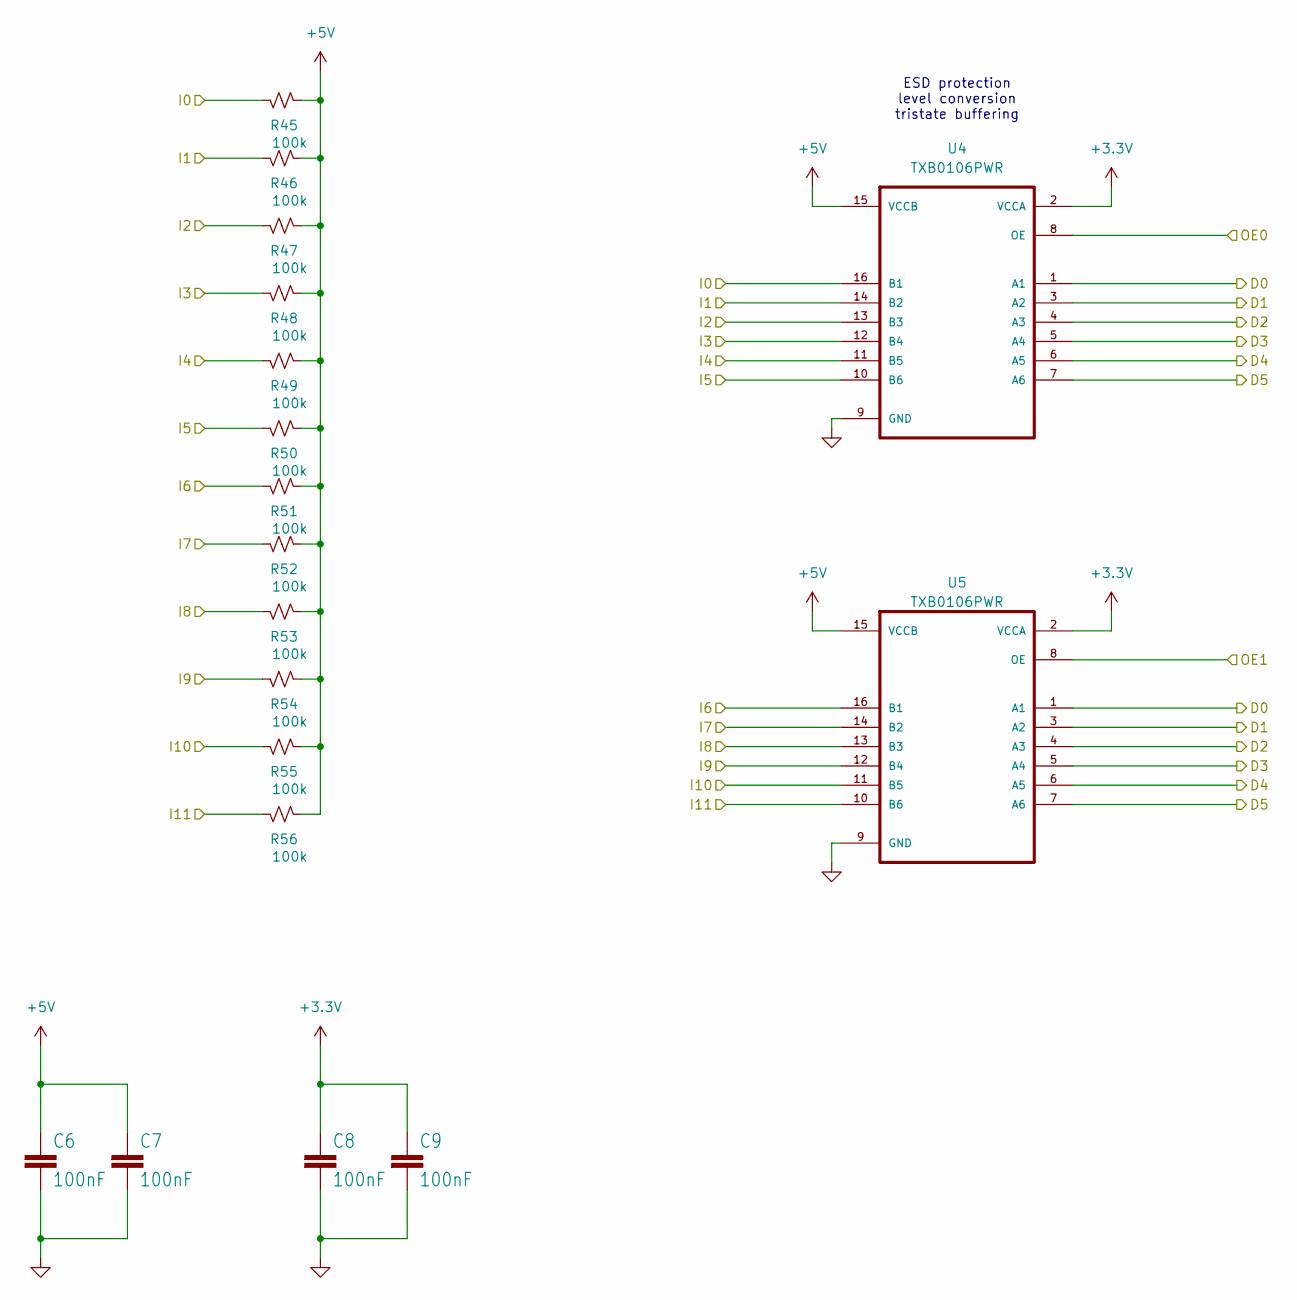
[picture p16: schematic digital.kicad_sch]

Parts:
C6, C7, C8, C9: 100nF; C_0402_1005Metric; LCSC C307331
R45, R46, R47, R48, R49, R50, R51, R52, R53, R54, R55, R56: 100k; R_0402_1005Metric; LCSC C25741
U4, U5: TXB0106PWR; SOP65P640X120-16N; DigiKey_Part_Number 296-23759-2-ND

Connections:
+3.3V: C8.1, C9.1, U4.2 (VCCA), U5.2 (VCCA); also elsewhere on the board
+5V: C6.1, C7.1, R45.2, R46.2, R47.2, R48.2, R49.2, R50.2, R51.2, R52.2, R53.2, R54.2, R55.2, R56.2, U4.15 (VCCB), U5.15 (VCCB); also elsewhere on the board
/CLK_P10: U4.8 (OE); also elsewhere on the board
/CLK_P11: U5.8 (OE); also elsewhere on the board
/D0: U4.1 (A1), U5.1 (A1); also elsewhere on the board
/D1: U4.3 (A2), U5.3 (A2); also elsewhere on the board
/D2: U4.4 (A3), U5.4 (A3); also elsewhere on the board
/D3: U4.5 (A4), U5.5 (A4); also elsewhere on the board
/D4: U4.6 (A5), U5.6 (A5); also elsewhere on the board
/D5: U4.7 (A6), U5.7 (A6); also elsewhere on the board
/Input P1/I11: R56.1, U5.10 (B6)
/JAMMA_P1_BUTTON1: R48.1, U4.12 (B4); also elsewhere on the board
/JAMMA_P1_BUTTON2: R47.1, U4.13 (B3); also elsewhere on the board
/JAMMA_P1_BUTTON3: R46.1, U4.14 (B2); also elsewhere on the board
/JAMMA_P1_BUTTON4: R45.1, U4.16 (B1); also elsewhere on the board
/JAMMA_P1_COIN: R54.1, U5.12 (B4); also elsewhere on the board
/JAMMA_P1_D: R51.1, U5.16 (B1); also elsewhere on the board
/JAMMA_P1_L: R50.1, U4.10 (B6); also elsewhere on the board
/JAMMA_P1_R: R49.1, U4.11 (B5); also elsewhere on the board
/JAMMA_P1_START: R53.1, U5.13 (B3); also elsewhere on the board
/JAMMA_P1_U: R52.1, U5.14 (B2); also elsewhere on the board
/JAMMA_TEST: R55.1, U5.11 (B5); also elsewhere on the board
GND: C6.2, C7.2, C8.2, C9.2, U4.9 (GND), U5.9 (GND); also elsewhere on the board

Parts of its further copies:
C10, C11, C12, C13: 100nF; C_0402_1005Metric; LCSC C307331
R59, R60, R83, R84, R85, R86, R87, R88, R89, R90, R91, R92: 100k; R_0402_1005Metric; LCSC C25741
U6, U10: TXB0106PWR; SOP65P640X120-16N; DigiKey_Part_Number 296-23759-2-ND

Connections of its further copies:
+3.3V: C12.1, C13.1, U6.2 (VCCA), U10.2 (VCCA); also elsewhere on the board
+5V: C10.1, C11.1, R59.2, R60.2, R83.2, R84.2, R85.2, R86.2, R87.2, R88.2, R89.2, R90.2, R91.2, R92.2, U6.15 (VCCB), U10.15 (VCCB); also elsewhere on the board
/CLK_P20: U6.8 (OE); also elsewhere on the board
/CLK_P21: U10.8 (OE); also elsewhere on the board
/D0: U6.1 (A1), U10.1 (A1); also elsewhere on the board
/D1: U6.3 (A2), U10.3 (A2); also elsewhere on the board
/D2: U6.4 (A3), U10.4 (A3); also elsewhere on the board
/D3: U6.5 (A4), U10.5 (A4); also elsewhere on the board
/D4: U6.6 (A5), U10.6 (A5); also elsewhere on the board
/D5: U6.7 (A6), U10.7 (A6); also elsewhere on the board
/JAMMA_P2_BUTTON1: R84.1, U6.12 (B4); also elsewhere on the board
/JAMMA_P2_BUTTON2: R83.1, U6.13 (B3); also elsewhere on the board
/JAMMA_P2_BUTTON3: R60.1, U6.14 (B2); also elsewhere on the board
/JAMMA_P2_BUTTON4: R59.1, U6.16 (B1); also elsewhere on the board
/JAMMA_P2_COIN: R90.1, U10.12 (B4); also elsewhere on the board
/JAMMA_P2_D: R87.1, U10.16 (B1); also elsewhere on the board
/JAMMA_P2_L: R86.1, U6.10 (B6); also elsewhere on the board
/JAMMA_P2_R: R85.1, U6.11 (B5); also elsewhere on the board
/JAMMA_P2_START: R89.1, U10.13 (B3); also elsewhere on the board
/JAMMA_P2_U: R88.1, U10.14 (B2); also elsewhere on the board
/JAMMA_SERVICE: R92.1, U10.10 (B6); also elsewhere on the board
/JAMMA_TILT: R91.1, U10.11 (B5); also elsewhere on the board
GND: C10.2, C11.2, C12.2, C13.2, U6.9 (GND), U10.9 (GND); also elsewhere on the board

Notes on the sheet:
ESD protection level conversion tristate buffering

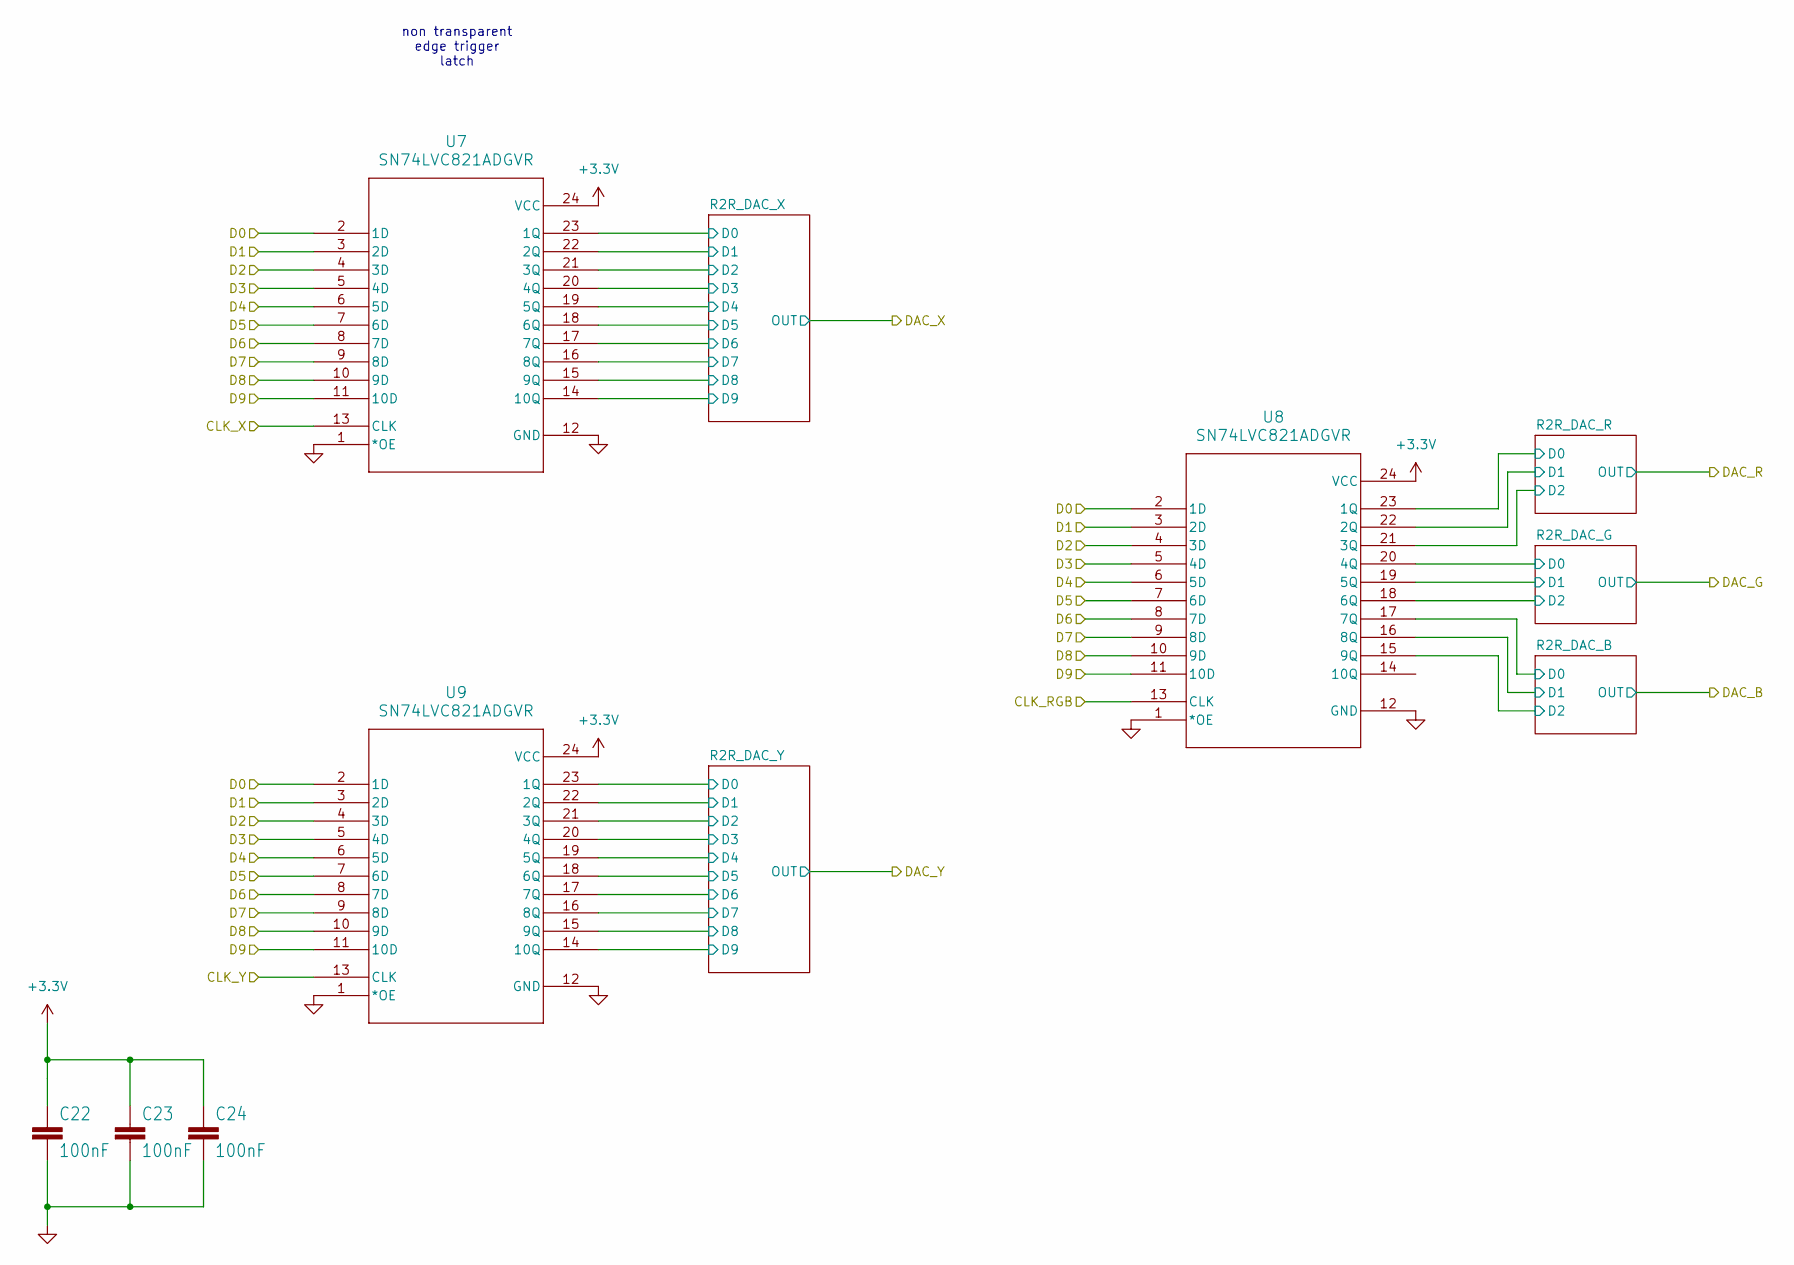
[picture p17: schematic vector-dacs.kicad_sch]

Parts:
C22, C23, C24: 100nF; C_0402_1005Metric; LCSC C307331
U7, U8, U9: SN74LVC821ADGVR; LCSC C2869439

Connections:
+3.3V: C22.1, C23.1, C24.1, U7.24 (VCC), U8.24 (VCC), U9.24 (VCC); also elsewhere on the board
/CLK_RGB: U8.13 (CLK); also elsewhere on the board
/CLK_X: U7.13 (CLK); also elsewhere on the board
/CLK_Y: U9.13 (CLK); also elsewhere on the board
/D0: U7.2 (1D), U8.2 (1D), U9.2 (1D); also elsewhere on the board
/D1: U7.3 (2D), U8.3 (2D), U9.3 (2D); also elsewhere on the board
/D2: U7.4 (3D), U8.4 (3D), U9.4 (3D); also elsewhere on the board
/D3: U7.5 (4D), U8.5 (4D), U9.5 (4D); also elsewhere on the board
/D4: U7.6 (5D), U8.6 (5D), U9.6 (5D); also elsewhere on the board
/D5: U7.7 (6D), U8.7 (6D), U9.7 (6D); also elsewhere on the board
/D6: U7.8 (7D), U8.8 (7D), U9.8 (7D); also elsewhere on the board
/D7: U7.9 (8D), U8.9 (8D), U9.9 (8D); also elsewhere on the board
/D8: U7.10 (9D), U8.10 (9D), U9.10 (9D); also elsewhere on the board
/D9: U7.11 (10D), U8.11 (10D), U9.11 (10D); also elsewhere on the board
/Vector DACs/R2R_DAC_B/D0: U8.17 (7Q); also elsewhere on the board
/Vector DACs/R2R_DAC_B/D1: U8.16 (8Q); also elsewhere on the board
/Vector DACs/R2R_DAC_B/D2: U8.15 (9Q); also elsewhere on the board
/Vector DACs/R2R_DAC_G/D0: U8.20 (4Q); also elsewhere on the board
/Vector DACs/R2R_DAC_G/D1: U8.19 (5Q); also elsewhere on the board
/Vector DACs/R2R_DAC_G/D2: U8.18 (6Q); also elsewhere on the board
/Vector DACs/R2R_DAC_R/D0: U8.23 (1Q); also elsewhere on the board
/Vector DACs/R2R_DAC_R/D1: U8.22 (2Q); also elsewhere on the board
/Vector DACs/R2R_DAC_R/D2: U8.21 (3Q); also elsewhere on the board
/Vector DACs/R2R_DAC_X/D0: U7.23 (1Q); also elsewhere on the board
/Vector DACs/R2R_DAC_X/D1: U7.22 (2Q); also elsewhere on the board
/Vector DACs/R2R_DAC_X/D2: U7.21 (3Q); also elsewhere on the board
/Vector DACs/R2R_DAC_X/D3: U7.20 (4Q); also elsewhere on the board
/Vector DACs/R2R_DAC_X/D4: U7.19 (5Q); also elsewhere on the board
/Vector DACs/R2R_DAC_X/D5: U7.18 (6Q); also elsewhere on the board
/Vector DACs/R2R_DAC_X/D6: U7.17 (7Q); also elsewhere on the board
/Vector DACs/R2R_DAC_X/D7: U7.16 (8Q); also elsewhere on the board
/Vector DACs/R2R_DAC_X/D8: U7.15 (9Q); also elsewhere on the board
/Vector DACs/R2R_DAC_X/D9: U7.14 (10Q); also elsewhere on the board
/Vector DACs/R2R_DAC_Y/D0: U9.23 (1Q); also elsewhere on the board
/Vector DACs/R2R_DAC_Y/D1: U9.22 (2Q); also elsewhere on the board
/Vector DACs/R2R_DAC_Y/D2: U9.21 (3Q); also elsewhere on the board
/Vector DACs/R2R_DAC_Y/D3: U9.20 (4Q); also elsewhere on the board
/Vector DACs/R2R_DAC_Y/D4: U9.19 (5Q); also elsewhere on the board
/Vector DACs/R2R_DAC_Y/D5: U9.18 (6Q); also elsewhere on the board
/Vector DACs/R2R_DAC_Y/D6: U9.17 (7Q); also elsewhere on the board
/Vector DACs/R2R_DAC_Y/D7: U9.16 (8Q); also elsewhere on the board
/Vector DACs/R2R_DAC_Y/D8: U9.15 (9Q); also elsewhere on the board
/Vector DACs/R2R_DAC_Y/D9: U9.14 (10Q); also elsewhere on the board
GND: C22.2, C23.2, C24.2, U7.1 (*OE), U7.12 (GND), U8.1 (*OE), U8.12 (GND), U9.1 (*OE), U9.12 (GND); also elsewhere on the board

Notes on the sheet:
non transparent edge trigger latch

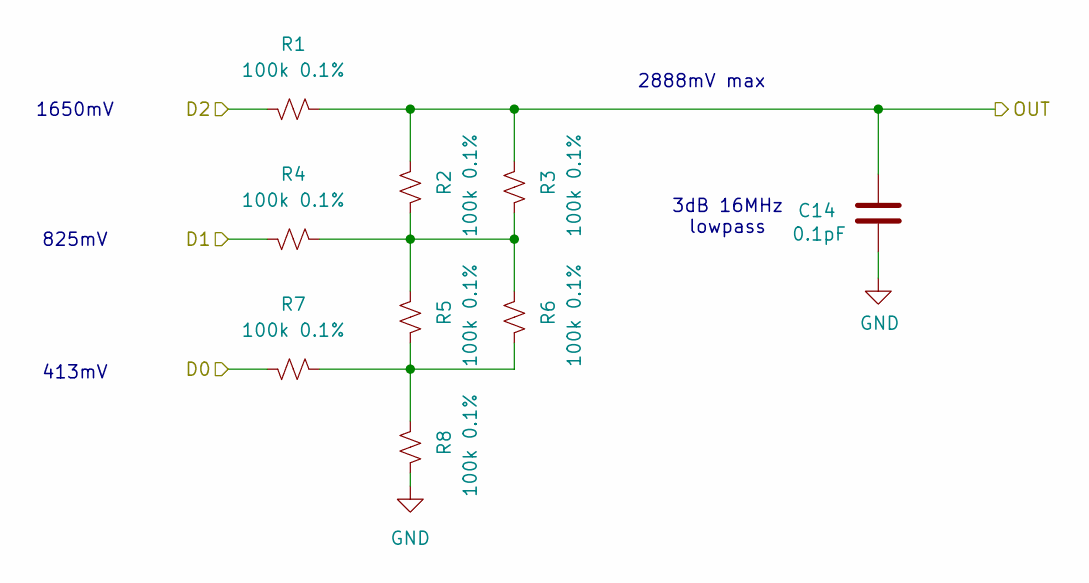
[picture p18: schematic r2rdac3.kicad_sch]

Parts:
C14: 0.1pF; C_0402_1005Metric; LCSC C5448807
R1, R2, R3, R4, R5, R6, R7, R8: 100k 0.1%; R_0402_1005Metric; LCSC C852472

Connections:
/Vector Amplifiers/DAC_B: C14.2, R1.1, R2.1, R3.1; also elsewhere on the board
/Vector DACs/R2R_DAC_B/D0: R7.2; also elsewhere on the board
/Vector DACs/R2R_DAC_B/D1: R4.2; also elsewhere on the board
/Vector DACs/R2R_DAC_B/D2: R1.2; also elsewhere on the board
GND: C14.1, R8.2; also elsewhere on the board
unnamed: R2.2, R3.2, R4.1, R5.1, R6.1
unnamed: R5.2, R6.2, R7.1, R8.1

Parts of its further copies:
C15, C27: 0.1pF; C_0402_1005Metric; LCSC C5448807
R9, R10, R11, R12, R13, R14, R15, R16, R17, R18, R19, R20, R21, R22, R23, R24: 100k 0.1%; R_0402_1005Metric; LCSC C852472

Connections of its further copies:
/Vector Amplifiers/DAC_G: C15.2, R9.1, R10.1, R11.1; also elsewhere on the board
/Vector Amplifiers/DAC_R: C27.2, R17.1, R18.1, R19.1; also elsewhere on the board
/Vector DACs/R2R_DAC_G/D0: R15.2; also elsewhere on the board
/Vector DACs/R2R_DAC_G/D1: R12.2; also elsewhere on the board
/Vector DACs/R2R_DAC_G/D2: R9.2; also elsewhere on the board
/Vector DACs/R2R_DAC_R/D0: R23.2; also elsewhere on the board
/Vector DACs/R2R_DAC_R/D1: R20.2; also elsewhere on the board
/Vector DACs/R2R_DAC_R/D2: R17.2; also elsewhere on the board
GND: C15.1, C27.1, R16.2, R24.2; also elsewhere on the board
unnamed: R10.2, R11.2, R12.1, R13.1, R14.1
unnamed: R13.2, R14.2, R15.1, R16.1
unnamed: R18.2, R19.2, R20.1, R21.1, R22.1
unnamed: R21.2, R22.2, R23.1, R24.1

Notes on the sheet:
2888mV max
3dB 16MHz lowpass
413mV
825mV
1650mV

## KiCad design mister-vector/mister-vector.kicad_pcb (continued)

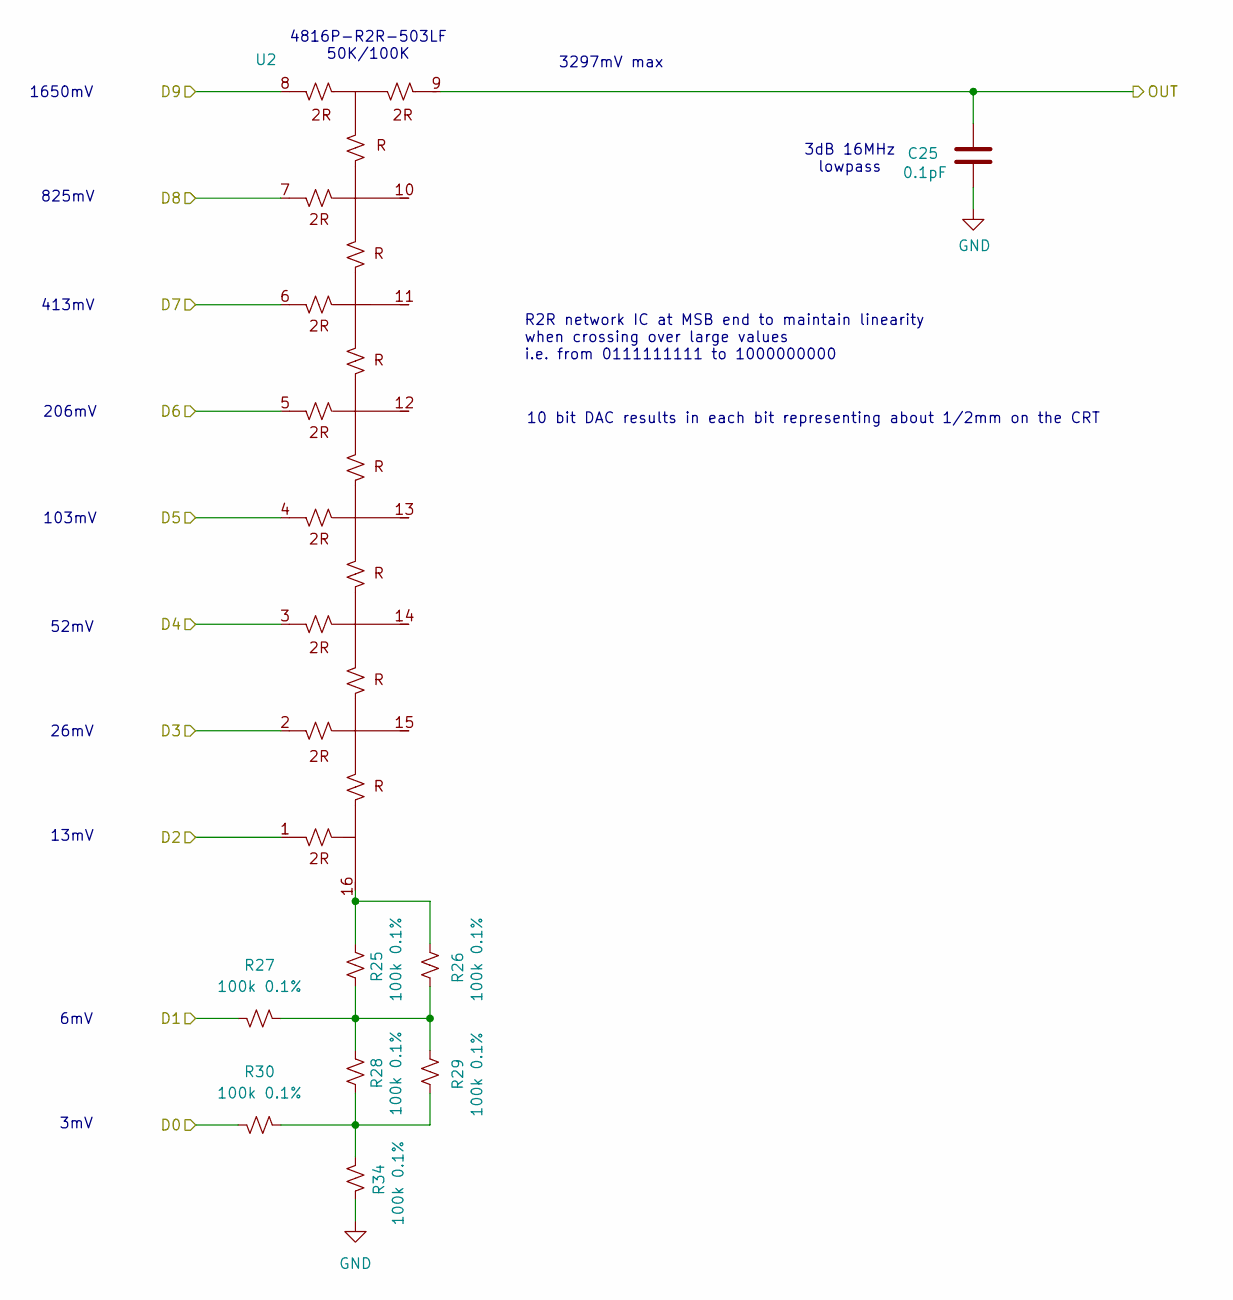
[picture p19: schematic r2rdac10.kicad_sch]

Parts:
C25: 0.1pF; C_0402_1005Metric; LCSC C5448807
R25, R26, R27, R28, R29, R30, R34: 100k 0.1%; R_0402_1005Metric; LCSC C852472
U2: 4816P-R2R-503LF; SOIC-16W_5.3x10.2mm_P1.27mm; LCSC C1518174

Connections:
/Vector Amplifiers/DAC_X: C25.2, U2.9; also elsewhere on the board
/Vector DACs/R2R_DAC_X/D0: R30.2; also elsewhere on the board
/Vector DACs/R2R_DAC_X/D1: R27.2; also elsewhere on the board
/Vector DACs/R2R_DAC_X/D2: U2.1; also elsewhere on the board
/Vector DACs/R2R_DAC_X/D3: U2.2; also elsewhere on the board
/Vector DACs/R2R_DAC_X/D4: U2.3; also elsewhere on the board
/Vector DACs/R2R_DAC_X/D5: U2.4; also elsewhere on the board
/Vector DACs/R2R_DAC_X/D6: U2.5; also elsewhere on the board
/Vector DACs/R2R_DAC_X/D7: U2.6; also elsewhere on the board
/Vector DACs/R2R_DAC_X/D8: U2.7; also elsewhere on the board
/Vector DACs/R2R_DAC_X/D9: U2.8; also elsewhere on the board
GND: C25.1, R34.2; also elsewhere on the board
unnamed: R25.1, R26.1, U2.16
unnamed: R25.2, R26.2, R27.1, R28.1, R29.1
unnamed: R28.2, R29.2, R30.1, R34.1

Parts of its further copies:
C26: 0.1pF; C_0402_1005Metric; LCSC C5448807
R35, R36, R37, R38, R39, R40, R44: 100k 0.1%; R_0402_1005Metric; LCSC C852472
U3: 4816P-R2R-503LF; SOIC-16W_5.3x10.2mm_P1.27mm; LCSC C1518174

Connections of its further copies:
/Vector Amplifiers/DAC_Y: C26.2, U3.9; also elsewhere on the board
/Vector DACs/R2R_DAC_Y/D0: R40.2; also elsewhere on the board
/Vector DACs/R2R_DAC_Y/D1: R37.2; also elsewhere on the board
/Vector DACs/R2R_DAC_Y/D2: U3.1; also elsewhere on the board
/Vector DACs/R2R_DAC_Y/D3: U3.2; also elsewhere on the board
/Vector DACs/R2R_DAC_Y/D4: U3.3; also elsewhere on the board
/Vector DACs/R2R_DAC_Y/D5: U3.4; also elsewhere on the board
/Vector DACs/R2R_DAC_Y/D6: U3.5; also elsewhere on the board
/Vector DACs/R2R_DAC_Y/D7: U3.6; also elsewhere on the board
/Vector DACs/R2R_DAC_Y/D8: U3.7; also elsewhere on the board
/Vector DACs/R2R_DAC_Y/D9: U3.8; also elsewhere on the board
GND: C26.1, R44.2; also elsewhere on the board
unnamed: R35.1, R36.1, U3.16
unnamed: R35.2, R36.2, R37.1, R38.1, R39.1
unnamed: R38.2, R39.2, R40.1, R44.1

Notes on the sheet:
103mV
R2R network IC at MSB end to maintain linearity when crossing over large values i.e. from 0111111111 to 1000000000
52mV
4816P-R2R-503LF 50K/100K
13mV
3297mV max
26mV
3mV
10 bit DAC results in each bit representing about 1/2mm on the CRT
6mV
1650mV
3dB 16MHz lowpass
413mV
206mV
825mV

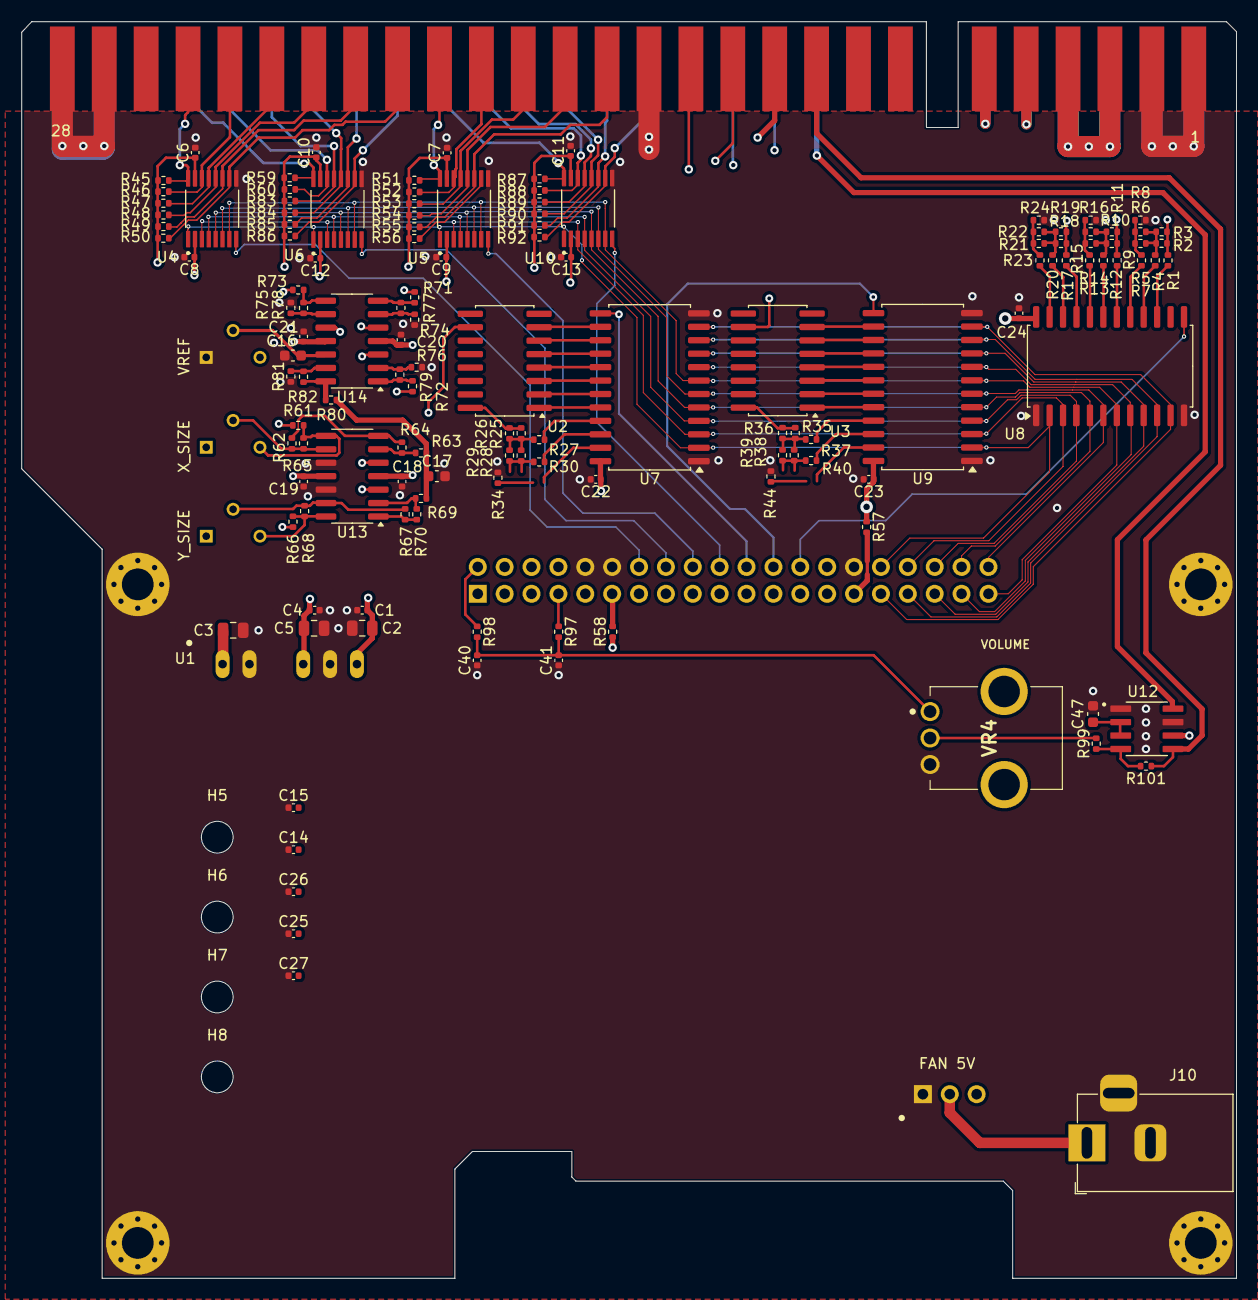
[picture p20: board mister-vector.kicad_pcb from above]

Board: 4 copper layers, 114.8 x 118.8 mm, 149 parts (1 on the bottom side), 127 nets.

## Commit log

2025-05-30 convert to kicad
    [MiSTer Vector 2.0.brd, MiSTer Vector 2.0.sch, mister-vector.kicad_pcb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]
2025-05-31 relink refdegs
    [mister-vector.kicad_pcb]
2025-06-03 reworking for r2r-dac and edge triggered buffers
    [ladderdac.kicad_sch, mister-vector.kicad_pcb, mister-vector.kicad_sch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]
2025-08-31 hierarchical schematic, add libraries
    [BOM-mister-vector.csv, analog.kicad_sch, audio.kicad_sch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]
2025-08-31 update pcb screenshot
    [mister-vector.kicad_pcb]

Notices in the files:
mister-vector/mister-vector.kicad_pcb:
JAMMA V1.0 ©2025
